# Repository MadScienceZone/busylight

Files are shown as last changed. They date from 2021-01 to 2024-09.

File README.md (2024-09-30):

# ARCHIVED
As of September, 2024, this project is archived. Another project which has long been in the works,
[Readerboard](https://github.com/MadScienceZone/readerboard), defines hardware, firmware, and software
to drive LED matrix displays which happen to also include an 8-LED status indicator display which exactly
mirrors the operation of a Busylight unit. As such, a Readerboard unit is a proper superset of a Busylight
unit, so it made sense to merge the Busylight project into it.

Going forward, the firmware for both Busylights and Readerboards is compiled from a common source code base,
which we consider preferable to maintaining two separate but similar code bases.  Over on the Readerboard
project there are also a number of hardware improvements over the older Busylight units archived here.

# busylight
DIY computer "do not disturb" indicator

This was a weekend project to see if I could take the stuff in my junk drawer and implement a simple light that would show my family members if it was safe to interrupt me without accidentally having their voices or faces appear in a meeting (this is during the work-at-home pandemic restrictions).

## Operation
The light is placed in a convenient and visible location, and displays lights to indicate my current "busy" state.
This version of the Busylight project allows for up to 7 lights of arbitrary colors.

My original used these colors:
* Green: interrupt at will.
* Yellow: interrupt if important (this is shown if I happen to have anything scheduled on my Google calendars, such as a meeting or just some time blocked out to focus on a project)
* Red: in a meeting (this is shown if I'm actually connected to a video conference meeting)
* Flashing red: in a meeting, and my microphone is unmuted
* Flashing blue/red: urgent status
* Strobing green: (along with other lights) low-priority meeting, be aware I'm on camera but interruptions are ok

## Hardware
For the light itself, I grabbed a spare Arduino Pro Micro board, a ULN2003A darlington transistor array chip, and a bunch of LEDs and resistors and threw them together.
I chose resistor values to get a suitable brightness from the LEDs (which varied by color and the voltage ratings of the LEDs; your mileage may vary) without overloading
the USB supply current limits.

The Arduino board and LEDs are powered by the USB port from the host PC, as well as using that connection for the host to send serial commands to control the lights.

To make this easier, I created a shield PCB to neatly interface the high current driver chip to an 8-bin DIN connector for the light tree.

## Software
On the PC, the normal mode of operation is to run the `busylightd` daemon. This monitors a set of Google calendars and reports busy/free times with the green and yellow
lights. It also responds to external signals from other processes which can inform it of other status changes.

In my case, I used [Hammerspoon](https://www.hammerspoon.org) which provides extensible automation capabilities for MacOS systems, including a very handy plugin that detects
when you join or leave a Zoom call, and tracks the state of the mute controls while in the meeting. I just configured that to send the appropriate signals to the
*busylightd* process when those statuses changed.

The upshot of that is that I can leave this running, put busy time on my calendars, join Zoom calls, and so forth, while the light indicator automatically displays
the appropriate colors.

### API Access
To get access to the Google calendar API, you'll need to register with Google and get an API key. If I were distributing this as a pre-made app, I'd include my API key
with the distribution, but as a DIY project, if you make one of these based on my design, you're essentially creating your own app anyway so it makes sense to get a
separate API key for yours.

### Documentation
There's a *busylight(1)* manual page included which explains the setup and operation of the software.

A schematic of how I wired up the hardware is also included, although it's fairly trivial, and can be adjusted to suit your needs.

### GUI Tool
A simple tcl/tk script is supplied which provides a convenient front-end to the *busylight* program, with the addition of task time tracking.

A *blight(1)* manual page is provided to explain it.

# Release notes
See the `CHANGELOG.md` file.

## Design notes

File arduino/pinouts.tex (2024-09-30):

\chapter{Connector Pinouts}
\section{Full-Duplex RS-485 Connection (8p8c Female Modular Jacks)}
\begin{center}
\begin{tikzpicture}[scale=.25]
	\draw [thick] (0,0) -- (0,13) -- (13,13) -- (13,0) -- cycle;
	\draw (2,11) -- (11,11) -- (11,4) -- (9,4) -- (9,3) -- (8,3) -- (8,2) -- (5,2) -- (5,3) -- (4,3) -- (4,4) -- (2,4) -- cycle;
	\foreach \x in {3, 4, 5, 6, 7, 8, 9, 10} {
		\draw (\x,11) -- (\x,8);
	}
	\node [below] at (3,8) {1};
	\node [below] at (10,8) {8};
	\node [right] at (15,12) {\strut 1 Return Data ($+$) (W/Or)};
	\node [right] at (15,10.5) {\strut 2 Return Data ($-$) (Or)};
	\node [right] at (15,9) {\strut 3 Cable Check (W/Gr)};
	\node [right] at (15,7.5)  {\strut 4 Data ($-$) (Bl)};
	\node [right] at (15,6)  {\strut 5 Data ($+$) (W/Bl)};
	\node [right] at (15,4.5)  {\strut 6 Cable Check (Gr)};
	\node [right] at (15,3)  {\strut 7 Data Ground (W/Br)};
	\node [right] at (15,1.5)  {\strut 8 Return Data Ground (Br)};
\end{tikzpicture}
\end{center}

\section{Half-Duplex RS-485 Connection (6p6c Female Modular Jacks)}
\begin{center}
\begin{tikzpicture}[scale=.25]
	\draw [thick] (0,0) -- (0,13) -- (13,13) -- (13,0) -- cycle;
	\draw (2,11) -- (11,11) -- (11,4) -- (9,4) -- (9,3) -- (8,3) -- (8,2) -- (5,2) -- (5,3) -- (4,3) -- (4,4) -- (2,4) -- cycle;
	\foreach \x in {4, 5, 6, 7, 8, 9} {
		\draw (\x,11) -- (\x,8);
	}
	\node [below] at (4,8) {1};
	\node [below] at (9,8) {6};
	\node [right] at (15,12) {\strut 1 Cable Check (W/Gn)};
	\node [right] at (15,10.5) {\strut 2 Data Ground (W/Br)};
	\node [right] at (15,9) {\strut 3 Data ($-$) (Bl)};
	\node [right] at (15,7.5)  {\strut 4 Data ($+$) (W/Bl)};
	\node [right] at (15,6)  {\strut 5 Data Ground (Br)};
	\node [right] at (15,4.5)  {\strut 6 Cable Check (Gn)};
%	\node [right] at (15,3)  {\strut 7 Data Ground};
%	\node [right] at (15,1.5)  {\strut 8 Return Data Ground};
\end{tikzpicture}
\end{center}
%Note that the jacks are labeled ``\mc{IN}'' and ``\mc{OUT/THRU}'' on the board.  This is intended to remind the user
%that these are daisy-chained connections with a signal coming ``in'' to the board on one wire, and on ``through'' to
%the next board in the circuit.% (or ``out'' back to the host PC in the case of responses to query commands).  
%These
%names also mirror the naming conventions used with \acronym{DMX} equipment. 
%
%Electrically, however, the RS-485 serial ``network'' is a single bus running from the host PC to the last Lumos
%controller.  Each controller ``taps'' into the line as it goes by.  This means that, labeling notwithstanding,
%the ``\mc{IN}'' and ``\mc{OUT/THRU}'' jacks are in fact completely identical and interchangeable.
%
%The ``cable check'' lines are simply passed through the Lumos board from input to output, with the expectation that
%the terminator will connect them together.  These lines are not used by Lumos boards at all.  They are provided as
%a convenient way for the host PC interface to verify cable continuity by sending a voltage down one pin all
%the way to the terminator and back on the other pin.  This helps warn the user if a cable becomes disconnected.
%The Lumos front panel circuit board is one example of a circuit which makes use of this feature.
%
%The two grounds on pins 7 and 8 are actually shorted together and connected to the common signal ground
%on the Lumos board.
%
%If connecting a Lumos board to a \acronym{DMX} controller, an adapter cable is needed to connect the
%\acronym{DMX} \acronym{DIN} plug to the 8-pin modular plug used on the Lumos board.  A typical adapter is wired as shown in Table~\ref{tbl:dmx8p}, but check your equipment in case it is different.
%\begin{table}
% \begin{center}
%  \begin{tabular}{ccc}\toprule
%	\bfseries Signal &
%	\bfseries \acronym{DMX} \acronym{DIN} Connector &
%	\bfseries Lumos Modular Connector\\\midrule
%	Ground & 1 & 7, 8 \\
%	Data ($-$) & 2 & 4 \\
%	Data ($+$) & 3 & 5 \\\bottomrule
%  \end{tabular}
%  \caption{Typical Wiring Arrangement to Adapt \acronym{DMX} to Lumos\label{tbl:dmx8p}}
% \end{center}
%\end{table}
%
%\newpage
%
%\section{RS-485 Terminator (8p8c Male Plug)}
%The terminator plug consists of a pair of 120\,$\Omega$ resistors.  One is connected across pins 1--2, and the other
%across pins 4--5.  This provides the proper line termination at the end of the RS-485 chain.  A terminator must
%be plugged in to each end of the chain (but note that often the PC's RS-485 adaptor contains a built-in terminator).
%
%To enable the cable check feature to work, pins 3 and 6 must also be shorted together.
%
%The schematic diagram for the terminator is included below.  Often, the resistors are mounted to a small circuit
%board which fits inside the modular plug, making a self-contained terminator plug.\label{sch:terminator}
%\begin{center}
%	\begin{circuitikz}
%		\draw (0,0) -- (1,0) -- (1,4.5) -- (0,4.5) -- cycle;
%		\node at (.5,.5) {8};
%		\node at (.5,1) {7};
%		\node at (.5,1.5) {6};
%		\node at (.5,2) {5};
%		\node at (.5,2.5) {4};
%		\node at (.5,3) {3};
%		\node at (.5,3.5) {2};
%		\node at (.5,4) {1};
%		\draw (1,4) to[R, l=120\,$\Omega$] (3,4);
%		\draw (3,4) -- (3,3.5) -- (1,3.5);
%		\draw (1,2.5) to[R] (3,2.5);
%		\draw (3,2.5) -- (3,2.0) -- (1,2.0);
%		\draw (1,3) -- (4,3) -- (4,1.5) -- (1,1.5);
%	\end{circuitikz}
%\end{center}
%
%\section{RS-232 Serial Connection (9-pin Female DE-9 Jack)}
%\begin{center}
%	\begin{tikzpicture}[scale=.25]
%		\draw [thick] (0,7) -- (12,7) -- (10,3) -- (2,3) -- cycle;
%		\foreach \x in {2, 4, 6, 8, 10} {
%			\draw (\x, 6) circle (.5);
%		}
%		\foreach \x in {3, 5, 7, 9} {
%			\draw (\x, 4) circle (.5);
%		}
%		\node [above] at (10,7) {1};
%		\node [above] at (2,7) {5};
%		\node [below] at (3,3) {9};
%		\node [below] at (9,3) {6};
%		\node [right] at (14,7) {2 Receive Data\strut};
%		\node [right] at (14,5.5) {3 Transmit Data\strut};
%		\node [right] at (14, 4) {4 Data Terminal Ready\strut};
%		\node [right] at (14, 2.5) {5 Signal Ground\strut};
%		\node [right] at (30, 7) {6 Data Set Ready\strut};
%		\node [right] at (30, 5.5) {7 Request to Send\strut};
%		\node [right] at (30, 4) {8 Clear to Send\strut};
%	\end{tikzpicture}
%\end{center}
%For Lumos boards configured to use RS-232 serial connections to a host PC, a standard 9-pin connector is used,
%with the Lumos board wired as a \acronym{DCE} device.
%
%On the Lumos board, Data Terminal Ready (\acronym{DTR}) and Data Set Ready (\acronym{DSR}) on pins 4 and 6 are shorted
%together, as are Request to Send (\acronym{RTS}) and Clear to Send (\acronym{CTS}) on pins 7 and 8.  This should satisfy
%most communications software which expects to see these signals present, although the Lumos board itself does not
%perform any hardware or software handshaking.
%
%Receive Data (\acronym{RxD}) and Transmit Data (\acronym{TxD}) are named from the point of view of the \acronym{DTE} (host
%PC), so \acronym{TxD} is the wire which carries data from the host PC to the Lumos board.
%
%\section{Sensor Input Terminals (J16)}
%\begin{center}
%	\begin{tikzpicture}[scale=.5]
%		\draw [thick] (.5,.5) -- (5.5,.5) -- (5.5,1.5) -- (.5,1.5) -- cycle;
%		\foreach \x in {1, 2, 3, 4, 5} {
%			\draw (\x,1) circle (.4);
%		}
%		\draw [thick] (4.5, .5) -- (4.5, 1.5);
%		\node [above] at (1,1.5) {$\overline{\hbox{A}}$};
%		\node [above] at (2,1.5) {$\overline{\hbox{B}}$};
%		\node [above] at (3,1.5) {$\overline{\hbox{C}}$};
%		\node [above] at (4,1.5) {$\overline{\hbox{D}}$};
%		\node [above right] at (4.5,1.5) {$\overline{\hbox{PWR CTL}}$};
%		\node [left] at (.5,1) {J16};
%		\node [right] at (5.5,1) {J9};
%		\draw (4,.4) -- (3.8,.1) -- (4.2,.1) -- cycle;
%		\draw (5,.4) -- (4.8,.1) -- (5.2,.1) -- cycle;
%	\end{tikzpicture}
%\end{center}
%If the Lumos controller is built to accommodate one or more sensor inputs, a set of terminals will be installed
%at J16, next to the $\overline{\hbox{\mc{PWR CTL}}}$ output at J9.  These are labeled from left to right (as the board
%is viewed right-side-up from the front) as 
%$\overline{\hbox{\mc{A}}}$,
%$\overline{\hbox{\mc{B}}}$,
%$\overline{\hbox{\mc{C}}}$, 
%and
%$\overline{\hbox{\mc{D}}}$.
%It is important to note that the board's circuitry must be configured for certain inputs to be enabled
%at the time the board is built, and that the board must be configured (using software) to recognize those
%inputs, before they will be usable.
%
%Each input accepts a \acronym{TTL}-level signal.  The lines are pulled up to +5\,V internally.  The board
%can be configured in software to react to the inputs as active-high or active-low.
%
%\section{Logic Output Terminals (J18)}
%\begin{center}
%	\begin{tikzpicture}[scale=.5]
%		\draw [thick] (.5,.5) -- (5.5,.5) -- (5.5,1.5) -- (.5,1.5) -- cycle;
%		\foreach \x in {1, 2, 3, 4, 5} {
%			\draw (\x,1) circle (.4);
%		}
%		\node [above] at (1,1.5) {0};
%		\node [above] at (2,1.5) {1};
%		\node [above] at (3,1.5) {2};
%		\node [above] at (4,1.5) {3};
%		\node [above right] at (4.5,1.5) {GND};
%		\node [left] at (.5,1) {J18};
%	\end{tikzpicture}
%\end{center}
%For experimental use, \acronym{TTL}-level outputs for the first four channels are available on J18.  These
%are active-low outputs, where a ``low'' (0) state indicates that the output should be on, and a ``high''
%(1) state means that the output should be off.  Note that if an output is at a dimmer level other than
%fully on or fully off, the signal will pulse with a duty cycle corresponding to the dimmer level as illustrated
%in Figure~\ref{fig:dutycycle}.
%
%%15
%%14...........
%%13------------
%%12............
%%11
%%10...........
%% 9------------
%% 8............
%% 7
%% 6...........
%% 5------------
%% 4............
%% 3
%% 2...........
%% 1------------
%% 0............
%
%\input dutycycle
%
%\section{ICSP Header (J11)}
%\begin{center}
%	\begin{tikzpicture}[scale=.5]
%		\draw [line width=10] (.6,1)--(5.4,1);
%		\foreach \x in {1, 2, 3, 4, 5} {
%			\foreach \y in {1} {
%				\draw [fill=white] (\x-.2,\y-.2) -- (\x-.2,\y+.2) -- (\x+.2,\y+.2) -- (\x+.2,\y-.2) -- cycle;
%			}
%		}
%		\draw (5.5,1) -- (6,1.25) -- (6,0.75) -- cycle;
%		\node [above] at (1,1.5) {5};
%		\node [above] at (2,1.5) {4};
%		\node [above] at (3,1.5) {3};
%		\node [above] at (4,1.5) {2};
%		\node [above] at (5,1.5) {1};
%		\node [right] at (7, 3.0) {1 $\hbox{V}_{\hbox{\footnotesize DD}}$ (+5\,V)};
%		\node [right] at (7, 2.0) {2 $\hbox{V}_{\hbox{\footnotesize SS}}$ (Ground)};
%		\node [right] at (7, 1.0) {3 $\hbox{V}_{\hbox{\footnotesize PP}}/\overline{\hbox{\mc{MCLR}}}/\overline{\hbox{\mc{RESET}}}$};
%		\node [right] at (15, 3.0) {4 PGD$/\overline{\hbox{\mc{PWR CTL}}}$};
%		\node [right] at (15, 2.0) {5 PGC$/\overline{\hbox{\mc{OPTION}}}$};
%	\end{tikzpicture}
%\end{center}
%
%This header is used for reprogramming a new firmware image onto the microcontroller chip.  Be sure to check the pinout
%used by your programmer before connecting it to this port.  It may be different!
%
%During normal operations, this header may also be used to connect off-board buttons for the reset and option functions.  These
%buttons should be normally open, but connect their respective pins to ground when pushed. 
%Note that the $\overline{\hbox{\mc{PWR CTL}}}$ output is also present on pin~4 of J11 in addition to its normal
%terminal at J9.
%
%
%\section{Voltage Select Headers (J6--J8, J17)}\label{sec:voltagesw}
%\begin{center}
%	\begin{tikzpicture}[scale=.5]
%		%\draw [line width=10] (.6,1)--(4.4,1);
%		\draw [line width=10] (1,.6)--(1,4.4);
%		\draw [line width=10] (5,.6)--(5,4.4);
%		\foreach \y in {1, 2, 3, 4} {
%			\foreach \x in {1, 5} {
%				\draw [fill=white] (\x-.2,\y-.2) -- (\x-.2,\y+.2) -- (\x+.2,\y+.2) -- (\x+.2,\y-.2) -- cycle;
%			}
%		}
%		\node [above] at (1,4.4) {J17};
%		\node [above] at (5,4.4) {J6--J8};
%		\node [left] at (.8,1) {VRO};
%		\node [left] at (.8,2) {+O};
%		\node [left] at (.8,3) {+I};
%		\node [left] at (.8,4) {VRI};
%		\node [left] at (4.8,1) {VRI};
%		\node [left] at (4.8,2) {+I};
%		\node [left] at (4.8,3) {+O};
%		\node [left] at (4.8,4) {VRO};
%
%		\node [right] at (7, 4) {+I: Positive voltage in from power supply};
%		\node [right] at (7, 3) {+O: Positive voltage out to circuit};
%		\node [right] at (7, 2) {VRI: Input to voltage regulator};
%		\node [right] at (7, 1) {VRO: Output from voltage regulator};
%	\end{tikzpicture}
%\end{center}
%J6--J8 are used to select the input voltage supplied to the power control blocks for channels 0--7, 8--15, and 16--23
%respectively.  Likewise, J17 selects the input voltage supplied to the logic portion of the board.  Although the pinouts
%are mirrored between J17 and the others, their operation is the same.  If a regulated +5\,V supply is employed, there is no
%need for the on-board regulator (and in fact it can't function properly unless its input is at least +8\,V), so a jumper
%is placed across the middle two pins (connecting +I and +O), bypassing the voltage regulator entirely.  \emph{In this 
%case, it is critically important that the input voltage be a clean, regulated +5\,V supply.  If this voltage is exceeded,
%permanent damage to the Lumos board will result!}
%
%If +8\,V to +24\,V is attached to an input, the corresponding jumper block needs jumpers installed into the outer two pins,
%connecting +I to VRI and +O to VRO.  This routes the incoming power through the voltage regulator.
%
%\input{voltagedpdt}
%
%\section{Relay Control Connection (26-pin Male IDC Header)}
%%
%%   . . . . . . . . . . . . .
%%   . . . . . . . . . . . . .
%%
%\begin{center}
%	\begin{tikzpicture}[scale=.25]
%		\foreach \x in {1, 2, 3, 4, 5, 6, 7, 8, 9, 10, 11, 12, 13} {
%			\foreach \y in {1, 2} {
%				\draw (\x-.1,\y-.1) -- (\x-.1,\y+.1) -- (\x+.1,\y+.1) -- (\x+.1,\y-.1) -- cycle;
%			}
%		}
%		%\draw         (.4,.4) -- (.4,2.6) -- (13.6,2.6) -- (13.6,.4) -- (.4,.4);
%		\draw         (.4,.4) -- (.4,2.6) -- (13.6,2.6) -- (13.6,.4) -- (8,.4) -- (8,.2) -- (6,.2) -- (6,.4) -- cycle;
%		\draw [thick] (.2,.2) -- (.2,2.8) -- (13.8,2.8) -- (13.8,.2) -- cycle;
%		\node [below] at (1,0) {\strut1};
%		\node [above] at (1,3) {\strut2};
%%		\node [below] at (2,0) {\strut3};
%%		\node [above] at (2,3) {\strut4};
%		\node [below] at (3.5,0) {\strut$\cdots$};
%		\node [above] at (3.5,3) {\strut$\cdots$};
%		\node [below] at (13,0) {\strut 25};
%		\node [above] at (13,3) {\strut 26};
%	\end{tikzpicture}
%\end{center}
%For Lumos controllers built as ``dumb'' relay boards with no built-in logic control of their own, a 26-pin 
%\acronym{IDC} ribbon cable header is installed at J14.  This is used to connect the relays to the controlling circuit (e.g.,
%a Lumos 48-channel controller).  The pinout of this header is:
%\begin{center}
%	\begin{tabular}{rl|rl|rl|rl}
%1&$\overline{\hbox{\mc{SSR23}}}$&8&$\overline{\hbox{\mc{SSR3}}}$&15&Gnd                           &22&$\overline{\hbox{\mc{SSR9}}}$ \\
%2&$\overline{\hbox{\mc{SSR0}}}$&9&$\overline{\hbox{\mc{SSR19}}}$&16&+5\,V                         &23&$\overline{\hbox{\mc{SSR13}}}$ \\
%3&$\overline{\hbox{\mc{SSR22}}}$&10&$\overline{\hbox{\mc{SSR4}}}$&17&$\overline{\hbox{\mc{SSR16}}}$&24&$\overline{\hbox{\mc{SSR10}}}$ \\
%4&$\overline{\hbox{\mc{SSR1}}}$&11&$\overline{\hbox{\mc{SSR18}}}$&18&$\overline{\hbox{\mc{SSR7}}}$&25&$\overline{\hbox{\mc{SSR12}}}$\\
%5&$\overline{\hbox{\mc{SSR21}}}$&12&$\overline{\hbox{\mc{SSR5}}}$&19&$\overline{\hbox{\mc{SSR15}}}$&26&$\overline{\hbox{\mc{SSR11}}}$\\
%6&$\overline{\hbox{\mc{SSR2}}}$&13&$\overline{\hbox{\mc{SSR17}}}$&20&$\overline{\hbox{\mc{SSR8}}}$\\
%7&$\overline{\hbox{\mc{SSR20}}}$&14&$\overline{\hbox{\mc{SSR6}}}$&21&$\overline{\hbox{\mc{SSR14}}}$
%	\end{tabular}
%\end{center}

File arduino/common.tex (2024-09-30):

% @[10]@| Copyright © 1992–2023 by Steven L. Willoughby (AKA MadScienceZone)
% @[11]@| steve@madscience.zone (previously AKA Software Alchemy),
% @[12]@| Aloha, Oregon, USA. All Rights Reserved.
% @[13]@| Distributed under the terms and conditions of the BSD-3-Clause
% @[14]@| License as described in the accompanying LICENSE file distributed
% @[15]@| with GMA.
% @[16]@|
% @[20]@| Redistribution and use in source and binary forms, with or without
% @[21]@| modification, are permitted provided that the following conditions
% @[22]@| are met:
% @[23]@| 1. Redistributions of source code must retain the above copyright
% @[24]@|    notice, this list of conditions and the following disclaimer.
% @[25]@| 2. Redistributions in binary form must reproduce the above copy-
% @[26]@|    right notice, this list of conditions and the following dis-
% @[27]@|    claimer in the documentation and/or other materials provided
% @[28]@|    with the distribution.
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
\usepackage{amsmath}
\usepackage{amssymb}
\usepackage{bbding}
\usepackage{substr}
\usepackage[T1]{fontenc}
\usepackage{tgschola}
\usepackage{ucs}
\usepackage{siunitx}
\usepackage{colortbl}
\usepackage{longtable}
\usepackage{color}
\usepackage{calc}
\usepackage{graphicx}
\usepackage{soul}
\usepackage{xfrac}
\usepackage{wallpaper}
\usepackage{tikz}
\usepackage{verbatim}
\usepackage{algpseudocode}
\usepackage{algorithm}
\usepackage[colorlinks=true,linkcolor=blue]{hyperref}
\usepackage{enumitem}
\makeindex
\newcommand\ix[1]{#1\index{#1}}
%\makeglossary
%\showindexmarks
\nouppercaseheads
%\hideindexmarks
%
% Page Layout Parameters
%
\setstocksize{11in}{8.5in}        % printing on letter stock  8.5x11
%\settrimmedsize{234mm}{180mm}{*}  % trimmed paper dimensions ~7.5x9.5
%
% old sizes
%
%\settrimmedsize{234mm}{184mm}{*}  % trimmed paper dimensions ~7.5x9.5
%\settrims{23mm}{35mm}             % offset into stock of trimmed paper
%\settypeblocksize{182mm}{32pc}{*} % dimensions of type block
%\setlrmargins{*}{27mm}{*}         % margins 27mm from outer edge
%\setulmargins{*}{27mm}{*}         % margins 27mm from bottom edge
%\setheaderspaces{*}{12mm}{*}      % 12mm between header and text baselines
%\setmarginnotes{5mm}{15mm}{2mm}   % margin notes 15mm wide, 5mm from text, 2mm from each other
%
% new sizes
%
%%\settrimmedsize{257mm}{178mm}{*}  % trimmed paper dimensions 
%\settrimmedsize{257mm}{180.5mm}{*}% trimmed paper dimensions 
%%\settrims{12mm}{40mm}             % offset into stock of trimmed paper
%\settrims{12mm}{37mm}             % offset into stock of trimmed paper
%\settypeblocksize{205mm}{31pc}{*} % dimensions of type block
%\setlrmargins{*}{27mm}{*}         % margins 27mm from outer edge
%\setulmargins{*}{27mm}{*}         % margins 27mm from bottom edge
%\setheaderspaces{*}{12mm}{*}      % 12mm between header and text baselines
%\setmarginnotes{5mm}{15mm}{2mm}   % margin notes 15mm wide, 5mm from text, 2mm from each other
\fixpdflayout
%
\trimFrame
\checkandfixthelayout

  \definecolor{chapterboxcolor}{rgb}{.647,.129,.149}%
%\newcommand\defaultchaptercolor{%
%  \definecolor{chapterboxcolor}{rgb}{.051,.278,.631}%
%}
%\defaultchaptercolor
\makeatletter
\newlength\dlf@normtxtw
\setlength\dlf@normtxtw{\textwidth}
\def\myhelvetfont{\def\fdefault{mdput}}
\newsavebox{\feline@chapter}
\newcommand\feline@chapter@marker[1][4cm]{%
\sbox\feline@chapter{%
\resizebox{!}{#1}{\fboxsep=1pt%
%\colorbox{chapterboxcolor}{\color{white}\bfseries\sffamily\thechapter}%
\colorbox{chapterboxcolor}{\color{white}\bfseries\thechapter}%
}}%
\rotatebox{90}{%
\resizebox{%
\heightof{\usebox{\feline@chapter}}+\depthof{\usebox{\feline@chapter}}}%
{!}{\scshape\so\@chapapp}}\quad%
\raisebox{\depthof{\usebox{\feline@chapter}}}{\usebox{\feline@chapter}}%
}
\newcommand\feline@chm[1][4cm]{%
\sbox\feline@chapter{\feline@chapter@marker[#1]}%
\makebox[0pt][l]{% aka \rlap
\makebox[1cm][r]{\usebox\feline@chapter}%
}}
\makechapterstyle{daleif1}{
\renewcommand\chapnamefont{\normalfont\Large\scshape\raggedleft\so}
\renewcommand\chaptitlefont{\normalfont\huge\bfseries\scshape\color{chapterboxcolor}}
\renewcommand\chapternamenum{}
\renewcommand\printchaptername{}
\renewcommand\printchapternum{\null\hfill\feline@chm[2.5cm]\par}
\renewcommand\afterchapternum{\par\vskip\midchapskip}
\renewcommand\printchaptertitle[1]{\chaptitlefont\raggedleft ##1\par}
}
\makeatother
\chapterstyle{daleif1}

%\chapterstyle{veelo}
%\stockletter      % 8.5 x 11  in stock paper size
%\pagestatement    % 8.5 x 5.5 in page size
%\settrimmedsize{9in}{6in}{*}
%\settrims{1in}{1.25in}
%\setlrmarginsandblock{.5in}{.5in}{*}
%\setulmarginsandblock{1in}{1in}{*}
%\trimFrame
%\quarkmarks
%
% Footnote Setup
%
%
% Fix table of contents spacing
% @pnumwidth [1.55em] width of box holding page numbers in TOC
% @tocrmarg  [2.55em] title text indentation from right margin
% @dotsep    [4.5]    math units of space between TOC leader dots.
%
\makeatletter
\renewcommand{\@pnumwidth}{2.5em}
\makeatother
%
%
\begin{document}
\setlength{\epigraphrule}{0pt}
\newcommand\Qauthor[2][]{%
  \\%
  \textnormal{---#2%
    \ifthenelse{\equal{#1}{}}{}{%
      \\%
      {\footnotesize #1}%
    }%
  }%
}
%
% Indexing
% \ix{<text>} typesets <text> and indexes it too (identical in both
%             cases--to get something different, use \index explicitly).
%
% \LJquote[subtext]{author}{quote text}
%    Epigraph (a single quote).  The optional subtext is set smaller
%    in upright shape under the author.  Authors are given an em-dash
%    in caps and small caps fully flush right.  The quote text itself
%    is in Italics in a 40% width paragraph which is itself against the
%    right margin.
%
%    The author's name is indexed.  The following special syntax is
%    recognized for the {author} parameter:
%XXX    <text>      - index <text> after trying to change* to Lastname, First
%XXX    @<text>     - index <text> as-is*
%XXX    /<text>     - typeset <text> but do NOT index (use \index manually)
%
%XXX    <text>!<i>  - typeset as <text>, index as <i> using all the usual
%                     indexing controls in <i>.
%XXX    <text>!     - typeset <text> but do NOT index.
%
%    (*These functions are handled by external scripts which prepare the
%    indexes)
%
% \LJquote*[subtext]{author}{quote text}
%    Alternative for wider quotations (uses 60% width).
%
% \LJquote![subtext]{author}{quote text}
%    Alternative for narrow quotations (uses 25% width).
%
% \LJquotex[subtext]{author}{quote text}{width}
%    Extended and generalized form allowing you to specify your own
%    paragraph width.
%
% \index{...}	Index 
%				entry
%				entry!subentry
%				entry!subentry!subsubentry
%				entry@formatted-entry
%				entry|command			page# in \command{...}
%				entry|see {other-entry}
%				entry|seealso{other-entry}
%				entry@form!sub@form
%				entry|(   ... entry|)    	mark page range
%				"! "@ "| ""			literal !, @, |, "
%
           \newcommand\LJquote[3][]{\LJquotex[#1]{#2}{#3}{0.400\textwidth}}
\WithSuffix\newcommand\LJquote*[3][]{\LJquotex[#1]{#2}{#3}{0.60\textwidth}}
\WithSuffix\newcommand\LJquote![3][]{\LJquotex[#1]{#2}{#3}{0.25\textwidth}}
%
\newcommand\SuppressLjQuoteIndexing{norm}
\newcommand\LJqindex[1]{%
%  \index[quotes]{#1}%
  \index{$1}%
  \renewcommand\SuppressLjQuoteIndexing{nil}%
}
\WithSuffix\newcommand\LJqindex*{\renewcommand\SuppressLjQuoteIndexing{nil}}

\newcommand\LJquotex[4][]{%
  \setlength{\epigraphwidth}{#4}%
  \ifthenelse{\equal{\SuppressLjQuoteIndexing}{norm}}{%
    %\index[quotes]{#2}%
    \index{#2}%
    \IfCharInString{@}{#2}{%
      \IfBeforeSubStringEmpty{@}{#2}{%
%        \def\LJqAuthor{\BehindSubString{@}{#2}}%
	 \def\LJqAuthor{#2}%
      }{%
        \def\LJqAuthor{#2}%
      }%
    }{%
      \def\LJqAuthor{#2}%
    }%
  }{%
    \renewcommand\SuppressLjQuoteIndexing{norm}%
    \def\LJqAuthor{#2}%
  }%
  \ifthenelse{\equal{\LJqAuthor}{}}{%
    \epigraph{{\em #3}}{}}{
    \ifthenelse{\equal{#1}{}}{%
      \epigraph{{\em #3}}{{---\LJqAuthor}}%
    }{%
      \epigraph{{\em #3}}{{---\LJqAuthor}\\
{\footnotesize #1}}%
    }%
  }%
}

% \LJqindex*    Do not index author name at all for next quote
% \LJqindex{@i} Use <i> as index entry for next \LJquote
% \LJqindex{i}  Use <i> as index entry for next \LJquote, changing to Last, First format
% \LJquote[work]{author}{text}  Set quote and index author in Last, First format
% \LJquote[work]{@author}{text} Set quote and index author as-is

\maxsecnumdepth{chapter}
% SourceCode environment:
%   Typesets source code in a verbatim box.
%
\newenvironment{SourceCode}{\boxedverbatim}{\endboxedverbatim}
\newenvironment{SourceCode*}{\begin{tcolorbox}\verbatim}{\endverbatim\end{tcolorbox}}
%
% Coding environment:
%   Code verbatim inside |bars|
%   Variables in \Var[*]{...} command  * form uses <> brackets around name
%
% Coding* puts the text in a colored box
% Coding! is like Coding* but uses ` instead of | to toggle verbatim text
% Coding: is like Coding! but is flush left
%   
\newenvironment{Coding}{\MakeShortVerb{\|}}{\DeleteShortVerb{\|}}
\newenvironment{Coding*}{\begin{tcolorbox}\MakeShortVerb{\|}}{\DeleteShortVerb{\|}\end{tcolorbox}}
\newenvironment{Coding!}{\begin{tcolorbox}\MakeShortVerb{\`}}{\DeleteShortVerb{\`}\end{tcolorbox}}
\newenvironment{Coding:}{\begin{tcolorbox}\MakeShortVerb{\`}\begin{flushleft}}{\end{flushleft}\DeleteShortVerb{\`}\end{tcolorbox}}
\newcommand\Var[1]{{\itshape #1\/}}
\WithSuffix\newcommand\Var*[1]{$\langle${\itshape #1\/}$\rangle$}
%
% \LJversal{versal}{first word(s)}
%   Begin a chapter paragraph.  This is just like \LJstart but without the
%   meta-post information being printed.
%   (In fact, \LJstart calls \LJversal to do the initial text.)
%
\newcommand\LJversal[2]{%
 \ifthenelse{\equal{#1}{A}}{%
  \lettrine[lines=3,findent=-1.1em,nindent=.9em,slope=.6em]{#1}{#2}%---------------A
 }{%
  \ifthenelse{\equal{#1}{B}}{%
   \lettrine[lines=3,findent=-.4em]{#1}{#2}%---------------------------------------B
  }{%
   \ifthenelse{\equal{#1}{C}}{%
    \lettrine[lines=3,findent=-.2em]{#1}{#2}%--------------------------------------C
   }{%
    \ifthenelse{\equal{#1}{D}}{%
     \lettrine[lines=3,findent=-.4em]{#1}{#2}%-------------------------------------D
    }{%
     \ifthenelse{\equal{#1}{E}}{%
      \lettrine[lines=3,findent=-.2em]{#1}{#2}%------------------------------------E
     }{%
      \ifthenelse{\equal{#1}{G}}{%
       \lettrine[lines=3,findent=-.3em]{#1}{#2}%-----------------------------------G
      }{%
       \ifthenelse{\equal{#1}{I}}{%
        \lettrine[lines=3,findent=-.1em]{#1}{#2}%----------------------------------I
       }{%
        \ifthenelse{\equal{#1}{K}}{%
         \lettrine[lines=3,findent=+.1em]{#1}{#2}%---------------------------------K
        }{%
         \ifthenelse{\equal{#1}{L}}{%
          \lettrine[lines=3,findent=-1.1em,nindent=1.5em]{#1}{#2}%-----------------L
         }{%
          \ifthenelse{\equal{#1}{O}}{%
           \lettrine[lines=3,findent=-.3em]{#1}{#2}%-------------------------------O
          }{%
           \ifthenelse{\equal{#1}{Q}}{%
            \lettrine[lines=3,findent=-.3em]{#1}{#2}%------------------------------Q
           }{%
            \ifthenelse{\equal{#1}{R}}{%
             \lettrine[lines=3,findent=-.3em]{#1}{#2}%-----------------------------R
            }{%
             \ifthenelse{\equal{#1}{S}}{%
              \lettrine[lines=3,findent=-.2em]{#1}{#2}%----------------------------S
             }{%
              \ifthenelse{\equal{#1}{V}}{%
               \lettrine[lines=3,findent=+.1em,nindent=0em,slope=-.5em]{#1}{#2}%---V
              }{%
               \ifthenelse{\equal{#1}{W}}{%
                \lettrine[lines=3,nindent=-.1em,slope=-.4em]{#1}{#2}%--------------W
               }{%
                \ifthenelse{\equal{#1}{Y}}{%
                 \lettrine[lines=3,findent=+.1em,nindent=0em,slope=-.5em]{#1}{#2}%-Y
                }{%
                 \lettrine[lines=3]{#1}{#2}%---------------------------------------*
	        }%
               }%
	      }%
	     }%
            }%
           }%
          }%
         }%
        }%
       }%
      }%
     }%
    }%
   }%
  }%
 }%
}

%
% \LJimg[options]{filename}
%   Place an inline EPS image here in the text (this needs refinement)
%
\newcommand\LJimg[2][]{%
  \ifthenelse{\equal{#2}{}}{%
    \emph{XXX Image? #1 #2}%
    \typeout{Missing image name in LJimg!}%
  }{%
    \ifthenelse{\boolean{pdf}}{%
      \ifthenelse{\equal{#1}{}}{%
        %\epsfig{file=images/#2, width=\textwidth}%
	%
      }{%
        %\epsfig{file=images/#2, #1}%
	%
      }%
    }{%
      \ifthenelse{\equal{#1}{}}{%
        %\epsfig{file=eps/#2.eps, width=\textwidth}%
	%
      }{%
        %\epsfig{file=eps/#2.eps, #1}%
	%
      }%
    }%
  }%
}% 
%
%
% \URLref[*][text]{url}
%   Refer to a URL somehow (as <a href="url">text</a> would have been)
%   Starred form uses 2nd level of footnotes (for use within a footnote)
%
\newcommand\URLref[2][]{#1\footnote{\URL{#2}}}
\WithSuffix\newcommand\URLref*[2][]{#1\footnoteB{\URL{#2}}}
%
% \acronym{letters}
% \mc{letters}
%   Typesets all-caps in slightly smaller font.  \mc just does the
%   typesetting, while \acronym also adds an entry in the main index
%   for the term (maybe someday we'll add to the glossary as well).
%
\newcommand\acronym[1]{{\smaller #1}\index{#1@\acronym*{#1}}}
\newcommand\Acronym[2]{#1{\smaller #2}\index{#1#2@#1{\smaller#2}}}
\WithSuffix\newcommand\acronym*[1]{{\smaller #1}}
\WithSuffix\newcommand\Acronym*[2]{#1{\smaller #2}}
\newcommand\mc[1]{{\smaller #1}}
%
% \starsep[symbol]
%   Star paragraph section separator.  The default symbol is
%   a fancy asterisk from the dingbats font.
%
\newcommand\starsep[1][\Asterisk]{
	\medskip
	\centerline{#1\qquad#1\qquad#1\qquad#1}
	\medskip
}

%
% unfinished
%
%\tracingmacros=1
\newcommand\strong[1]{{\bfseries #1}}
\newcommand\TM{\texttrademark}
\newcommand\work[1]{\emph{#1}\index{#1@\work*{#1}}}
\WithSuffix\newcommand\work*[1]{\emph{#1}}
\WithSuffix\newcommand\work:[2]{\work*{#1}\index{#2@\work*{#2}}}
%\WithSuffix\newcommand\worki[2]{\emph{#1 #2}\index{#2, #1@\emph{#2, #1}}}
\newcommand\URL[1]{{\ttfamily #1}}

\newenvironment{LJwrapimg}[3]{%
 \begingroup\setlength\intextsep{0pt}%
  \begin{wrapfigure}{#1}{#2}%
   \LJimg[width=#2]{#3}%
  \end{wrapfigure}%
}{%
 \par\endgroup%
}

\newcommand\z[1]{{\ttfamily#1}}
\newcommand\zb[1]{{\ttfamily\bfseries#1}}

% Based on post from tex.stackexchange.com from Gonzalo Medina
%\newlength\widest
%\makeatletter
%\NewEnviron{ldescription}{%
% \vbox{%
%  \global\setlength\widest{0pt}%
%  \def\item[##1]{%
%   \settowidth\@tempdima{\textbf{##1}}%
%   \ifdim\@tempdima>\widest\global\setlength\widest{\@tempdima}\fi%
%  }%
%  \setbox0=\hbox{\BODY}%
% }
% \begin{description}[
%   leftmargin=\dimexpr\widest+0.5em\relax,
%   labelindent=0pt,
%   labelwidth=\widest]
%  \BODY
%  \end{description}%
%}
%\makeatother
\newenvironment{ldescription}[1]{\begin{description}[leftmargin=#1+.5em,labelindent=0pt,labelwidth=#1]}{\end{description}}
%
% the NewContent environment shows material recently added to the document.
%
\newenvironment{NewContent}{\begingroup\color{blue}}{\endgroup}

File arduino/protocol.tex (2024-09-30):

% TODO: add support for Lumos-compatible RS-485 protocol
\input common
\frontmatter
\definecolor{reservedslot}{gray}{0.8}
\newcommand\api{\acronym{API}}
\newcommand\pc{\acronym{PC}}
\newcommand\cli{\acronym{CLI}}
\newcommand\ascii{\acronym{ASCII}}
\newcommand\led{\acronym{LED}}
\newcommand\codetype[1]{\z{#1}}
\newcommand\ixz[1]{\index{#1@\z{#1}}\z{#1}}
\newcommand\tUnused{\cellcolor{gray!50}}
\newcommand\tControl{\cellcolor{yellow!50}}
\newcommand\tForbidden{\cellcolor{red!50}}
\newcommand\tSpecial{\cellcolor{blue!25}}
%\colorlet{tableheader}{blue!40}
%\colorlet{tablesubhead}{blue!20}
%\colorlet{recordbox}{blue!15}
%\colorlet{recordtext}{black}
%\usetikzlibrary{positioning,shapes,shadows,arrows}
%\tikzstyle{program}=[rectangle, draw=black, rounded corners, fill=recordbox, drop shadow,
%	anchor=north, text=recordtext, text width=2cm]
%\tikzstyle{instance}=[rectangle, draw=black, rounded corners, fill=green!15, drop shadow,
%	anchor=north, text=black, text width=3cm]
%\tikzstyle{line}=[-, thick]
%\tikzstyle{myarrow}=[->, >=triangle 45, thick]
\hypersetup{
	pdftitle={Busylight User's Guide},
	pdfkeywords={Open Source Status Light Hardware and Software},
	pdfauthor={Steve Willoughby / Mad Science Zone},
	pdfsubject={Busylight Project Documentation * (c) 2023 * Creative Commons Licensing (See Document for details)},
	colorlinks=true,
	linkcolor=blue!30!black,
}
\thispagestyle{empty}
	\begin{center}
		\Huge Busylight \\ User's Guide \\
		WORKING\\DRAFT
	\end{center}

\vfill
%\end{flushright}
\newpage
The information in this document, and the hardware and software it describes, are hobbyist
works created as an educational exercise and as a matter of personal interest for recreational
purposes.

It is not to be considered an industrial-grade or retail-worthy product.
It is assumed that the user has the necessary understanding and skill to use it appropriately.  The author makes NO
representation as to suitability or fitness for any purpose whatsoever, and disclaims any and all liability or 
warranty to the full extent permitted by applicable law.  It is explicitly not designed for use where the safety
of persons, animals, property, or anything of real value depends on the correct operation of the software.

\strut\vfill

\begin{center}\bfseries
	For busylight hardware version 1.0.2, and firmware version 2.0.0.
\end{center}

\strut\vfill

\noindent Copyright \copyright\ 2023 by Steven L. Willoughby
(aka MadScienceZone), Aloha, Oregon, USA. All Rights Reserved.
This document is released under the terms and conditions of the
Creative Commons ``Attribution-NoDerivs 3.0 Unported'' license.
In summary, you are free to use, reproduce, and redistribute this 
document provided you give full attribution to its author and do not
alter it or create derivative works from it.  See
\begin{center}
\href{http://creativecommons.org/licenses/by-nd-3.0}{http://creativecommons.org/licenses/by\-nd\-/\-3.0/} 
\end{center}
for the full set of licensing terms.

\begin{center}
\LJimg[width=.25in]{cc}\LJimg[width=.25in]{by}\LJimg[width=.25in]{nd}
\end{center}

\newpage
\tableofcontents
\newpage
\listoffigures
\listoftables
\mainmatter

%%%%%%%%%%%%%%%%%%%%%%%%%%%%%%%%%%%%%%%%%%%%%%%%%%%%%%%%%%%%%%%%%%%%%%%%%%%%%%%%%%%%%%%%%%%%%%%%%%%%
%  ____  ____   ___ _____ ___   ____ ___  _     
% |  _ \|  _ \ / _ \_   _/ _ \ / ___/ _ \| |    
% | |_) | |_) | | | || || | | | |  | | | | |    
% |  __/|  _ <| |_| || || |_| | |__| |_| | |___ 
% |_|   |_| \_\\___/ |_| \___/ \____\___/|_____|
%
\chapter{Protocol Description}\label{chap:protocol}
{\setlength{\epigraphwidth}{.5\textwidth}
\epigraph{Protocol is etiquette with a government expense account.}{---Judith Martin}}
\LJversal{T}{he protocol} used to control the busylight device is very simple.
Commands are expressed largely in plain \ascii\ characters and are executed immediately
as they are received.\footnote{Technically, they may even be executed \emph{while} they
are being received.}
%It is not necessarily required for a command to be fully received first,
%so it is possible that the unit will have started operating on part of the command (e.g.,
%moving the current cursor column position) even if the rest of the command could not be
%performed.

\section{USB vs. RS-485}
The protocol used to send commands to the busylight is different depending on
whether the host is sending directly to a single device over a \acronym{USB}
cable, or to (possibly) multiple devices over an RS-485 bus network.

This was designed for the Adruino Nano controller, which only has a single
\acronym{USART}, so the busylight will differentiate between \acronym{USB}
and RS-485 commands from their respective formats. On other units with multiple
serial ports, one is dedidated to the RS-485 network.

\subsection{USB}
A busylight connected via \acronym{USB} accepts the commands just as documented
below, with the addition that each such command is terminated by a 
\z{\textasciicircum D} byte (hex value \z{04}$_{16}$).
\begin{center}
\begin{bytefield}[endianness=little,bitwidth=0.11111\textwidth]{9}
	\bitbox[]{1}{\scriptsize0}&
	\bitbox[]{1}{\scriptsize\dots}&
	\bitbox[]{1}{\scriptsize$n-1$}&
	\bitbox[]{1}{\scriptsize$n$}\\
	\bitbox{3}{\Var*{command}}&
	\bitbox{1}{\z{\textasciicircum D}}
\end{bytefield}
\end{center}

If there is an error parsing or executing a command, the busylight will ignore
all subsequent input until a \z{\textasciicircum D} is received, whereupon it will
expect to see the start of another command. Thus, \z{\textasciicircum D} may not
appear in any transmitted data except to terminate commands.

\subsection{RS-485}
Commands sent over RS-485 are intended to target one or more of a set of
connected busylight units over a network which may also contain other Lumos-protocol-compatible
devices, so they use a protocol compatible with that use case.

Each command begins with one of the following binary headers, depending on the
set of target busylight units which should obey the command.

\subsubsection{Single Target or All Devices}
To send a command to a single unit, begin with a single byte encoded as:
\begin{center}
	\begin{bytefield}[endianness=big]{8}
		\bitheader{0-7} \\
		\bitbox{1}{\z{1}}&
		\bitbox[tbl]{1}{\z0}&
		\bitbox[tb]{1}{\z0}&
		\bitbox[tbr]{1}{\z1}&
		\bitbox{4}{\Var*{ad}}
	\end{bytefield}
\end{center}
where \Var*{ad} is the unit's address on the bus, which must be a value in the
range 0--15. This byte is followed by any command as described below. 
If the global address \Var{ad$_G$} is given as the \Var*{ad} value, then all busylight units
which have that set as their global address will obey the command.

\subsubsection{Multiple Targets}
Alternatively, a command may be targetted to multiple units by starting the command
with a multi-byte code:
\begin{center}
	\begin{bytefield}[endianness=big]{8}
		\bitheader{0-7} \\
		\bitbox{1}{\z{1}}&
		\bitbox[tbl]{1}{\z0}&
		\bitbox[tb]{1}{\z1}&
		\bitbox[tbr]{1}{\z1}&
		\bitbox{4}{\Var*{ad$_G$}}\\
		\bitbox{1}{\z0}&
%		\bitbox{3}{\color{reservedslot}\rule{\width}{\height}}&
%		\bitbox{4}{\Var*{n}}\\
		\bitbox{1}{\z0}&
		\bitbox{6}{\Var*{n}}\\
		\bitbox{1}{\z0}&
%		\bitbox{3}{\color{reservedslot}\rule{\width}{\height}}&
%		\bitbox{4}{\Var*{ad$_0$}}\\
		\bitbox{1}{\z0}&
		\bitbox{6}{\Var*{ad$_0$}}\\
		\bitbox[]{8}{$\vdots$\strut}\\
		\bitbox{1}{\z0}&
%		\bitbox{3}{\color{reservedslot}\rule{\width}{\height}}&
%		\bitbox{4}{\Var*{ad$_{n-1}$}}
		\bitbox{1}{\z0}&
		\bitbox{6}{\Var*{ad$_{n-1}$}}
	\end{bytefield}
\end{center}
where \Var*{ad$_G$} is the ``global'' device address which signals busylight units
generally (see the \z= command below).
This will send to the \Var*{n} devices addressed as \Var*{ad$_0$} through \Var*{ad$_{n-1}$}.

Note that the address of a unit is constrained to four bits (values 0--15) in the regular
command header, but the address values listed here are seven bits wide (values 0--63).
This allows you to give busylight devices address above 15, but if you do this, then
this multiple-target header must be used to send commands to them, since their addresses
won't fit in the shorter single-byte header.

\subsubsection{All Off}
As a special case, the single byte
\begin{center}
	\begin{bytefield}[endianness=big]{8}
		\bitheader{0-7} \\
		\bitbox{1}{\z{1}}&
		\bitbox[tbl]{1}{\z0}&
		\bitbox[tb]{1}{\z0}&
		\bitbox[tbr]{1}{\z0}&
		\bitbox{4}{\Var*{ad}}
	\end{bytefield}
\end{center}
will cause the busylight addressed as \Var*{ad} to turn off all \led s.
If \Var*{ad} is the \Var{ad$_G$} address, then all busylight units will turn off
all \led s.

No other command bytes need to follow; this byte is sufficient to turn off
the unit(s).

\subsubsection{Subsequent Command Bytes}
All subsequent bytes which follow the above binary headers \emph{must} have their
\acronym{MSB} cleared to \z0. 

To cover cases where a value sent as part of a command must have the \acronym{MSB}
set, we use the following escape codes:
\begin{itemize}
	\item A hex byte \z{7E}$_{16}$ causes the next byte received to have its
		\acronym{MSB} set upon receipt.
	\item A hex byte \z{7F}$_{16}$ causes the next byte to be accepted without
		any further interpretation.
\end{itemize}
Thus, the byte \z{C4}$_{16}$ is sent as the two-byte sequence \z{7E~44},
while a literal \z{7E} is sent as \z{7F~7E} and a literal \z{7F} as \z{7F~7F}.

If there is an error parsing or executing a command, the busylight will ignore
all subsequent input until a byte arrives with its \acronym{MSB} set to \z1,
whereupon it will expect to see the start of another command. 

\section{Command Summary}
\begin{table}
	\begin{center}
		\begin{tabular}{cll}\toprule
			\multicolumn{1}{c}{\bfseries Command}&
			\multicolumn{1}{c}{\bfseries Description}&
			\multicolumn{1}{c}{\bfseries Notes}\\\midrule
			\z{?} & Query discrete \led\ status & [1] [2]\\
			\z{=} & Set operational parameters & [2]\\
			\z{*} & Strobe \led s in Sequence & \\
			\z{F} & Flash \led s in Sequence & \\
			\z{L} & Light one or more \led s steady & \\
			\z{Q} & Query device status & [1] [2]\\
			\z{S} & Light one \led\ steady & \\
			\z{X} & All \led s off & \\
			\bottomrule
			\multicolumn{3}{l}{\footnotesize [1] Sends response}\\
			\multicolumn{3}{l}{\footnotesize [2] \acronym{USB} only}\\
		\end{tabular}
		\caption{Summary of All Commands\label{tbl:commands}}
	\end{center}
\end{table}

%Although the rev 2 hardware supports the ability to enable the RS-485 transmitter and send data back onto the network,
%this is not currently implemented by the firmware, and the intent is to have all devices listen passively to RS-485 traffic
%at all times.

\section{\z{*}---Strobe Lights in Sequence}
\begin{center}
\begin{bytefield}[endianness=little,bitwidth=0.11111\textwidth]{7}
%	\bitheader{0-3} \\
	\bitbox[]{1}{\scriptsize0}&
	\bitbox[]{1}{\scriptsize1}&
	\bitbox[]{1}{\scriptsize2}&
	\bitbox[]{1}{\scriptsize3}&
	\bitbox[]{1}{\scriptsize\dots}&
	\bitbox[]{1}{\scriptsize$n$}&
	\bitbox[]{1}{\scriptsize$n+1$}\\
	\bitbox{1}{\z{*}} &
	\bitbox[tlb]{1}{\Var*{led$_0$}} &
	\bitbox[tb]{1}{\Var*{led$_1$}} &
	\bitbox[tb]{1}{\Var*{led$_2$}} &
	\bitbox[tb]{1}{$\cdots$} &
	\bitbox[tbr]{1}{\Var*{led$_{n-1}$}} &
	\bitbox{1}{\z\$}
\end{bytefield}
\end{center}

Each \Var*{led} value is an \ascii\ character corresponding to a discrete
\led\ as shown in Table~\ref{tbl:lightcodes}. An \Var*{led} value of ``\z{\_}'' means
there is no \led\ illuminated at that point in the sequence.

This command functions identically to the \z{F} command (see below), except that the lights
are ``strobed'' (flashed very briefly with a pause between each light in the sequence).

\section{\z{=}---Set Operational Parameters}
\begin{center}
\begin{bytefield}[endianness=little,bitwidth=0.11111\textwidth]{8}
%	\bitheader{0-3} \\
	\bitbox[]{1}{\scriptsize0}&
	\bitbox[]{1}{\scriptsize1}&
	\bitbox[]{1}{\scriptsize2}&
	\bitbox[]{1}{\scriptsize3}&
	\bitbox[]{1}{\scriptsize4}\\
	\bitbox{1}{\z{=}} &
	\bitbox{1}{\Var*{ad}}&
	\bitbox{1}{\Var*{uspd}}&
	\bitbox{1}{\Var*{rspd}}&
	\bitbox{1}{\Var*{ad$_G$}}
\end{bytefield}
\end{center}

This command sets a few operational parameters for the unit. Once set, these will be persistent across
power cycles and reboots.

If the \Var*{ad} parameter is ``\z{\_}'' then the RS-485 interface is disabled entirely. Otherwise it is a
value from 0--63 encoded as described in Table~\ref{tbl:int063}. This enables the RS-485 interface and assigns
this unit's address to \Var*{ad}. Note that if you assign an address greater than 15 you can only address
the unit via multiple-target headers or via the global address.

The baud rate for the \acronym{USB} and RS-485 interfaces is set by the \Var*{uspd} and \Var*{rspd} values
respectively. Each is encoded as per Table~\ref{tbl:baudcodes}.

The \Var*{ad$_G$} value is an address in the range 0--15 which is not assigned
to any other device on the RS-485 network. This is used to signal that all
busylight units should pay attention to the start of the command because it might
target them either as part of a list of specific busylight units or because the
command is intended for all busylight units at once. This is encoded in the 
same way as \Var*{ad}.
If you only have one busylight or do no wish to assign a global address,
just set \Var*{ad$_G$} to the same value as \Var*{ad}.

This command may only be sent over the \acronym{USB} port.

By default, an unconfigured busylight is set to 9,600 baud with the RS-485 port disabled.
\begin{table}
	\begin{center}
		\begin{tabular}{crl}\toprule
			\bfseries Code & \multicolumn{1}{c}{\bfseries Speed} \\\midrule
			\z0 & 300\\
			\z1 & 600\\
			\z2 & 1,200\\
			\z3 & 2,400\\
			\z4 & 4,800\\
			\z5 & 9,600 & (default)\\
			\z6 & 14,400\\
			\z7 & 19,200\\
			\z8 & 28,800\\
			\z9 & 31,250\\
			\z{A} & 38,400\\
			\z{B} & 57,600\\
			\z{C} & 115,200\\
		\bottomrule
		\end{tabular}
		\caption{Baud Rate Codes\label{tbl:baudcodes}}
	\end{center}
\end{table}

\section{\z?---Query Discrete \led\ Status}
\begin{center}
\begin{bytefield}[endianness=little,bitwidth=0.11111\textwidth]{1}
	\bitheader{0} \\
	\bitbox{1}{\z{?}}
\end{bytefield}
\end{center}

This command causes the unit to send a status report back to the host to indicate
what the discrete \led s are currently showing. This response has the form:

\medskip

\begin{center}\begin{bytefield}[endianness=little,bitwidth=0.11111\textwidth]{9}
	\bitheader{0-8} \\
	\bitbox{1}{\z{L}} &
	\bitbox[tbl]{1}{\Var*{led$_0$}} &
	\bitbox[tb]{1}{\Var*{led$_1$}} &
	\bitbox[tb]{1}{\Var*{led$_2$}} &
	\bitbox[tb]{1}{\Var*{led$_3$}} &
	\bitbox[tb]{1}{\Var*{led$_4$}} &
	\bitbox[tb]{1}{\Var*{led$_5$}} &
	\bitbox[tb]{1}{\strut$\cdots$} &
	\bitbox[tbr]{1}{\Var*{led$_{n-1}$}} \\
	\bitbox{1}{\z{\$}} &
	\bitbox{1}{\z{F}} &
	\bitbox{7}{flasher status (see below)} \\
	\bitbox{1}{\z{\$}} &
	\bitbox{1}{\z{S}} &
	\bitbox{7}{strober status (see below)} \\
	\bitbox{1}{\z{\$}} &
	\bitbox{1}{\z{\textbackslash n}}
\end{bytefield}
\end{center}

Each \Var*{led$_x$} value is a single character which is ``\z{\_}'' if the corresponding \led\ is
off, or the \led's color code or position number if it is on. a ``\z{?}'' is sent if the value set
for the \led\ is invalid. One such value is sent for each \led\ installed
in the unit (typically seven for busylight units), followed by a ``\z{\$}'' to mark the end of the list.

The flasher and strober status values are variable-width fields which indicate the
state of the flasher (see \z{F} command) and strober (see \z{*} command) functions.
In each case, if there is no defined sequence, the status field will be:

\medskip

\begin{center}\begin{bytefield}[endianness=little,bitwidth=0.11111\textwidth]{2}
	\bitheader{0-1} \\
	\bitbox{1}{\Var*{run}} &
	\bitbox{1}{\strut\z{\_}}
\end{bytefield}
\end{center}

\smallskip

\noindent Otherwise, the state of the flasher or strober unit is indicated by:

\medskip

\begin{center}\begin{bytefield}[endianness=little,bitwidth=0.11111\textwidth]{7}
%	\bitheader{0-6} \\
	\bitbox[]{1}{\scriptsize0}&
	\bitbox[]{1}{\scriptsize1}&
	\bitbox[]{1}{\scriptsize2}&
	\bitbox[]{1}{\scriptsize3}&
	\bitbox[]{1}{\scriptsize4}&
	\bitbox[]{1}{\scriptsize\dots}&
	\bitbox[]{1}{\scriptsize$n+3$}\\
	\bitbox{1}{\Var*{run}} &
	\bitbox{1}{\Var*{pos}} &
	\bitbox{1}{\z{@}} &
	\bitbox[tbl]{1}{\Var*{led$_0$}} &
	\bitbox[tb]{1}{\Var*{led$_1$}} &
	\bitbox[tb]{1}{$\cdots$} &
	\bitbox[tbr]{1}{\Var*{led$_{n-1}$}} 
\end{bytefield}
\end{center}

In either case, \Var*{run} is the \ascii\ character ``\z{S}'' if the unit is
stopped or ``\z{R}'' if it is currently running.  If there is a defined sequence,
\Var*{pos} indicates the 0-origin position within the sequence of the light currently
being flashed or strobed, encoded as described in Table~\ref{tbl:int063}. 
The \Var*{led$_x$} values are as allowed for the \z{F} or \z{*}
command that set the sequence. (Regardless of the actual \z{F} or \z{*} command parameters,
the report will show symbolic color codes where possible, or numeric position codes otherwise.)

The status message sent to the host is terminated by a newline character (hex byte \z{0A}),
indicated in the protocol description above as ``\z{\textbackslash n}''.
\begin{table}
	\begin{center}
		\begin{tabular}{cc|cc}\toprule
			\multicolumn{1}{c}{\bfseries Value} &
			\multicolumn{1}{c}{\bfseries Code} &
			\multicolumn{1}{c}{\bfseries Value} &
			\multicolumn{1}{c}{\bfseries Code} \\\midrule
			0--9 & \z0--\z9 & 17--42 & \z{A}--\z{Z} \\
			10 & \z: & 43 & \z[ \\
			11 & \z; & 44 & \z\textbackslash \\
			12 & \z< & 45 & \z] \\
			13 & \z= & 46 & \z\textasciicircum \\
			14 & \z> & 47 & \z{\_} \\
			15 & \z? & 48 & \z` \\
			16 & \z@ & 49--63 & \z{a}--\z{o} \\
			\bottomrule
		\end{tabular}

		{\footnotesize (Each code is the numeric value plus 48.)}
		\caption{\ascii\ Encoded Integer Values (0--63)\label{tbl:int063}}
	\end{center}
\end{table}

This command may only be sent on the \acronym{USB} port.

\section{\z{F}---Flash Lights in Sequence}
\begin{center}
\begin{bytefield}[endianness=little,bitwidth=0.11111\textwidth]{7}
%	\bitheader{0-7} \\
	\bitbox[]{1}{\scriptsize0}&
	\bitbox[]{1}{\scriptsize1}&
	\bitbox[]{1}{\scriptsize2}&
	\bitbox[]{1}{\scriptsize3}&
	\bitbox[]{1}{\dots}&
	\bitbox[]{1}{\scriptsize$n$}&
	\bitbox[]{1}{\scriptsize$n+1$}\\
	\bitbox{1}{\z{F}} &
	\bitbox[tbl]{1}{\Var*{led$_0$}} &
	\bitbox[tb]{1}{\Var*{led$_1$}} &
	\bitbox[tb]{1}{\Var*{led$_2$}} &
	\bitbox[tb]{1}{$\cdots$} &
	\bitbox[tbr]{1}{\Var*{led$_{n-1}$}} &
	\bitbox{1}{\z\$}
\end{bytefield}
\end{center}

Each \Var*{led} value is an \ascii\ character corresponding to a discrete
\led\ as shown in Table~\ref{tbl:lightcodes}. Note that the assignment of colors
to these \led s is dependent on your particular hardware being assembled that way.
As an open source project, of course, you (or whomever assembled the unit) may choose any
color scheme you like when building the board.

An \Var*{led} value of ``\z{\_}'' means there is to be no \led\ illuminated at the
corresponding position in the sequence.
\begin{table}
	\begin{center}
		\begin{tabular}{ccl}\toprule
			\multicolumn{1}{c}{\bfseries Code*}&
			\multicolumn{1}{c}{\bfseries Light}&
			\multicolumn{1}{c}{\bfseries Color}\\\midrule
			\z{B} & L$_0$ & blue \\
			\z{R} & L$_1$ & red \\
			\z{r} & L$_2$ & red \\
			\z{Y} & L$_3$ & yellow \\
			\z{G} & L$_4$ & green \\
			\z{\_}& --- & (no \led/off) \\
			\z0--\z9&L$_0$--L$_9$&\led\ installed at physical position 0--9\\
			\bottomrule
		\end{tabular}\\
		{\footnotesize *If a unit is built with different colors in these positions, the letter codes\\ for those
		\led s will match the custom color arrangement for that unit.}
		\caption{Discrete \led\ Codes and Colors\label{tbl:lightcodes}}
	\end{center}
\end{table}

Up to 64 \Var*{led} codes may be listed. The unit will cycle through the sequence, lighting each
specified \led\ briefly before moving on to the next one. The sequence is repeated
forever in a loop until an \z{L}, \z{S} or \z{X} command is received. 

If only one \Var*{led} is specified, that light will be flashed on and off.
Setting an empty
sequence (no codes at all) stops the flasher's operation.

The sequence is terminated by either a dollar-sign (``\z{\$}'') character or the
escape control character (hex byte \z{1B}), indicated in the protocol diagram above
simply as ``\z{\$}''.
			
This command may be given in upper- or lower-case (``\z{f}'' or ``\z{F}'').

\section{\z{Q}---Query Device Status}
\begin{center}
\begin{bytefield}[endianness=little,bitwidth=0.11111\textwidth]{1}
	\bitheader{0} \\
	\bitbox{1}{\z{Q}} 
\end{bytefield}
\end{center}

This command causes the unit to send a status report back to the host to indicate
the general status of the device except for the discrete \led\ display which
may be queried using the \z? command. The response has the form:

\medskip

\begin{center}
\begin{bytefield}[endianness=little,bitwidth=0.11111\textwidth]{9}
%	\bitheader{0-8} \\
	\bitbox[]{1}{\scriptsize0}&
	\bitbox[]{1}{\scriptsize1}&
	\bitbox[]{1}{\scriptsize2}&
	\bitbox[]{1}{\scriptsize3}&
	\bitbox[]{1}{\scriptsize4}&
	\bitbox[]{1}{\scriptsize5}&
	\bitbox[]{1}{\scriptsize6}&
	\bitbox[]{1}{\scriptsize7}&
	\bitbox[]{1}{\scriptsize8}\\
	\bitbox{1}{\z{Q}} &
	\bitbox{1}{\Var*{model}} &
	\bitbox{1}{\z{=}} &
	\bitbox{1}{\Var*{ad}}&
	\bitbox{1}{\Var*{uspd}}&
	\bitbox{1}{\Var*{rspd}}&
	\bitbox{1}{\Var*{ad$_G$}}&
	\bitbox{1}{\z{\$}} &
	\bitbox{1}{\z{V}} \\
	\bitbox{2}{\Var*{hwversion}}
	\bitbox{1}{\z\$}&
	\bitbox{1}{\z{R}} &
	\bitbox{2}{\Var*{romversion}}&
	\bitbox{1}{\z{\$}}& 
	\bitbox{1}{\z{S}}& 
	\bitbox{1}{\Var*{serial}} \\
	\bitbox{1}{\z{\$}} &
	\bitbox{1}{\z{\textbackslash n}}
\end{bytefield}
\end{center}

The \Var*{model} field is ``\z{B}'' for the busylight hardware. Other codes
designate other compatible devices.

\Var*{hwversion} and \Var*{romversion} indicate the versions, respectively, of the 
hardware the firmware was compiled to drive, and of the firmware itself. Each of
these fields are variable-width and conform to the semantic version standard 2.0.0.\footnote{See
\href{https://semver.org}{semver.org}.} Each is terminated by a dollar-sign (\z\$) character (and
thus those strings may not contain dollar signs).

The \Var*{serial} field is a variable-width alphanumeric string which was set when the firm\-ware was
compiled. It should be a unique serial number for the device (although that depends on
some effort on the part of the person compiling the firmware to insert that serial number
each time). Serial numbers B000--B299 are reserved for the original author's use. This string is also
terminated with a dollar sign.

The \Var*{ad}, \Var*{uspd}, and \Var*{rspd} values are as last set by the \z= command (or the factory
defaults if they were never changed). If the serial device is disabled, ``\z{\_}'' is sent instead of
the baud rate code. Likewise, ``\z{\_}'' is sent for the address of a device for which no address
is set. ``\z{*}'' is sent for an address that is somehow invalid.

The status message sent to the host is terminated by a newline character (hex byte \z{0A}),
indicated in the protocol description above as ``\z{\textbackslash n}''.

\section{\z{S}---Light Single \led}
\begin{center}
\begin{bytefield}[endianness=little,bitwidth=0.11111\textwidth]{2}
	\bitheader{0-1} \\
	\bitbox{1}{\z{S}} &
	\bitbox{1}{\Var*{led}} 
\end{bytefield}
\end{center}

Stops the flasher (cancelling any previous \z{F} command) and turns off all discrete
\led s. The single \led\ indicated by \Var*{led} is turned on. See Table~\ref{tbl:lightcodes}. Note that if a strobe sequence is running (via a previous \z{*} command),
it remains running.

This command may be given in upper- or lower-case (``\z{s}'' or ``\z{S}'').

\section{\z{X}---Turn off Discrete \led s}
\begin{center}
\begin{bytefield}[endianness=little,bitwidth=0.11111\textwidth]{1}
	\bitheader{0} \\
	\bitbox{1}{\z{X}} 
\end{bytefield}
\end{center}

Turns off the flasher, strober, and all discrete \led s.

This command may be given in upper- or lower-case (``\z{x}'' or ``\z{X}'').

\input pinouts

\indexintoc

\printindex
\end{document}

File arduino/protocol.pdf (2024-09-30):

# Busylight

# User’s Guide

# WORKING

# DRAFT

ii

The information in this document, and the hardware and software it

describes, are hobbyist works created as an educational exercise and as a

matter of personal interest for recreational purposes.

It is not to be considered an industrial-grade or retail-worthy product.

It is assumed that the user has the necessary understanding and skill to

use it appropriately. The author makes NO representation as to suitability

or fitness for any purpose whatsoever, and disclaims any and all liability or

warranty to the full extent permitted by applicable law. It is explicitly not

designed for use where the safety of persons, animals, property, or anything

of real value depends on the correct operation of the software.

For busylight hardware version 1.0.2, and firmware version 2.0.0.

Copyright © 2023 by Steven L. Willoughby (aka MadScienceZone), Aloha,

Oregon, USA. All Rights Reserved. This document is released under the

terms and conditions of the Creative Commons “Attribution-NoDerivs 3.0

Unported” license. In summary, you are free to use, reproduce, and redis-

tribute this document provided you give full attribution to its author and

do not alter it or create derivative works from it. See

http://creativecommons.org/licenses/bynd/3.0/

for the full set of licensing terms.

# Contents

Contents | iii
List of Figures | iv
List of Tables | iv
1 | Protocol Description | 1
2 | Connector Pinouts | 9
| Full-Duplex RS-485 Connection (8p8c Female Modular Jacks) . | 9
| Half-Duplex RS-485 Connection (6p6c Female Modular Jacks) . | 9

## iii

# List of Figures

# List of Tables

1.1 | Summary of All Commands | | | 4
1.2 | Baud Rate Codes | | | 5
1.3 | ASCII Encoded Integer Values (0–63) | | 6
1.4 | Discrete LED Codes and Colors | | | 7

iv

# C h a p t e r

1

# Protocol Description

Protocol is etiquette with a government

expense account.

—Judith Martin
T

he protocol used to control the busylight device is very simple. Com-

mands are expressed largely in plain ASCII characters and are exe-

cuted immediately as they are received.1

# USB vs. RS-485

The protocol used to send commands to the busylight is different depending

on whether the host is sending directly to a single device over a USB cable,

or to (possibly) multiple devices over an RS-485 bus network.

This was designed for the Adruino Nano controller, which only has a

single USART, so the busylight will differentiate between USB and RS-485

commands from their respective formats. On other units with multiple

serial ports, one is dedidated to the RS-485 network.

## USB

A busylight connected via USB accepts the commands just as documented

below, with the addition that each such command is terminated by a ^D

byte (hex value 0416).

1Technically, they may even be executed while they are being received.

1

2 | Chapter 1. Protocol Description

0

. . . | n − 1 | n
⟨command⟩ | | ^D

If there is an error parsing or executing a command, the busylight will

ignore all subsequent input until a ^D is received, whereupon it will ex-

pect to see the start of another command. Thus, ^D may not appear in any

transmitted data except to terminate commands.

RS-485

Commands sent over RS-485 are intended to target one or more of a set

of connected busylight units over a network which may also contain other

Lumos-protocol-compatible devices, so they use a protocol compatible with

that use case.

Each command begins with one of the following binary headers, depend-

ing on the set of target busylight units which should obey the command.

Single Target or All Devices

To send a command to a single unit, begin with a single byte encoded as:

01234567
1 | 0 0 1 | ⟨ad⟩

where ⟨ad⟩ is the unit’s address on the bus, which must be a value in the

range 0–15. This byte is followed by any command as described below. If

the global address adG is given as the ⟨ad⟩ value, then all busylight units

which have that set as their global address will obey the command.

## Multiple Targets

Alternatively, a command may be targetted to multiple units by starting

the command with a multi-byte code:

01234567
1 | 0 1 1 | ⟨adG⟩
0 | 0 | ⟨n⟩
0 | 0 | ⟨ad0⟩
0 | 0 | ⟨adn−1⟩

where ⟨adG⟩ is the “global” device address which signals busylight units

generally (see the = command below). This will send to the ⟨n⟩ devices

addressed as ⟨ad0⟩ through ⟨adn−1⟩.

Note that the address of a unit is constrained to four bits (values 0–15) in

the regular command header, but the address values listed here are seven

Command Summary | 3

bits wide (values 0–63). This allows you to give busylight devices address

above 15, but if you do this, then this multiple-target header must be used

to send commands to them, since their addresses won’t fit in the shorter

single-byte header.

## All Off

As a special case, the single byte

01234567
1 | 0 0 0 | ⟨ad⟩

will cause the busylight addressed as ⟨ad⟩ to turn off all LEDs. If ⟨ad⟩ is the

adG address, then all busylight units will turn off all LEDs.

No other command bytes need to follow; this byte is sufficient to turn off

the unit(s).

Subsequent Command Bytes

All subsequent bytes which follow the above binary headers must have their

MSB cleared to 0.

To cover cases where a value sent as part of a command must have the

MSB set, we use the following escape codes:

- A hex byte 7E16 causes the next byte received to have its MSB set upon

receipt.

- A hex byte 7F16 causes the next byte to be accepted without any fur-

ther interpretation.

Thus, the byte C416 is sent as the two-byte sequence 7E 44, while a literal

7E is sent as 7F 7E and a literal 7F as 7F 7F.

If there is an error parsing or executing a command, the busylight will

ignore all subsequent input until a byte arrives with its MSB set to 1, where-

upon it will expect to see the start of another command.

### Command Summary

### *—Strobe Lights in Sequence

0 | 1 | 2 | 3 | . . . | n | n + 1
* | ⟨led0⟩ ⟨led1⟩ ⟨led2⟩ | · · · | ⟨ledn−1⟩ | $

Each ⟨led⟩ value is an ASCII character corresponding to a discrete LED as

shown in Table 1.4. An ⟨led⟩ value of “_” means there is no LED illuminated

at that point in the sequence.

4 | Chapter 1. Protocol Description
Command | Description | Notes
? | Query discrete LED status | [1] [2]
= | Set operational parameters | [2]
* | Strobe LEDs in Sequence
F | Flash LEDs in Sequence
L | Light one or more LEDs steady
Q | Query device status | [1] [2]
S | Light one LED steady
X | All LEDs off
[1] Sends response
[2] USB only

Table 1.1: Summary of All Commands

This command functions identically to the F command (see below), ex-

cept that the lights are “strobed” (flashed very briefly with a pause between

each light in the sequence).

### =—Set Operational Parameters

0 | 1 | 2 | 3 | 4
= | ⟨ad⟩ | ⟨uspd⟩ | ⟨rspd⟩ | ⟨adG⟩

This command sets a few operational parameters for the unit. Once set,

these will be persistent across power cycles and reboots.

If the ⟨ad⟩ parameter is “_” then the RS-485 interface is disabled en-

tirely. Otherwise it is a value from 0–63 encoded as described in Table 1.3.

This enables the RS-485 interface and assigns this unit’s address to ⟨ad⟩.

Note that if you assign an address greater than 15 you can only address

the unit via multiple-target headers or via the global address.

The baud rate for the USB and RS-485 interfaces is set by the ⟨uspd⟩ and

⟨rspd⟩ values respectively. Each is encoded as per Table 1.2.

The ⟨adG⟩ value is an address in the range 0–15 which is not assigned

to any other device on the RS-485 network. This is used to signal that all

busylight units should pay attention to the start of the command because

it might target them either as part of a list of specific busylight units or

because the command is intended for all busylight units at once. This is

encoded in the same way as ⟨ad⟩. If you only have one busylight or do no

wish to assign a global address, just set ⟨adG⟩ to the same value as ⟨ad⟩.

This command may only be sent over the USB port.

By default, an unconfigured busylight is set to 9,600 baud with the RS-

485 port disabled.

?—Query Discrete LED Status | 5
Code | Speed
0 | 300
1 | 600
2 | 1,200
3 | 2,400
4 | 4,800
5 | 9,600 | (default)
6 | 14,400
7 | 19,200
8 | 28,800
9 | 31,250
A | 38,400
B | 57,600
C | 115,200

Table 1.2: Baud Rate Codes

### ?—Query Discrete LED Status

0
?

This command causes the unit to send a status report back to the host

to indicate what the discrete LEDs are currently showing. This response

has the form:

0 | 1 | 2 | 3 | 4 | 5 | 6 | 7 | 8
L | ⟨led0⟩ ⟨led1⟩ ⟨led2⟩ ⟨led3⟩ ⟨led4⟩ ⟨led5⟩ · · · ⟨ledn−1⟩
$ | F | flasher status (see below)
$ | S | strober status (see below)
$ | \n

Each ⟨ledx⟩ value is a single character which is “_” if the corresponding

LED is off, or the LED’s color code or position number if it is on. a “?” is sent

if the value set for the LED is invalid. One such value is sent for each LED

installed in the unit (typically seven for busylight units), followed by a “$”

to mark the end of the list.

The flasher and strober status values are variable-width fields which

indicate the state of the flasher (see F command) and strober (see * com-

mand) functions. In each case, if there is no defined sequence, the status

## field will be:

6 | Chapter 1. Protocol Description
Value | Code | Value | Code
0–9 | 0–9 | 17–42 | A–Z
10 | : | 43 | [
11 | ; | 44 | \
12 | < | 45 | ]
13 | = | 46 | ^
14 | > | 47 | _
15 | ? | 48 | ‘
16 | @ | 49–63 | a–o

(Each code is the numeric value plus 48.)

Table 1.3: ASCII Encoded Integer Values (0–63)

0 | 1
⟨run⟩ | _

Otherwise, the state of the flasher or strober unit is indicated by:

0 | 1 | 2 | 3 | 4 | . . . | n + 3
⟨run⟩ | ⟨pos⟩ | @ | ⟨led0⟩ ⟨led1⟩ | · · · | ⟨ledn−1⟩

In either case, ⟨run⟩ is the ASCII character “S” if the unit is stopped or “R”

if it is currently running. If there is a defined sequence, ⟨pos⟩ indicates the

0-origin position within the sequence of the light currently being flashed or

strobed, encoded as described in Table 1.3. The ⟨ledx⟩ values are as allowed

for the F or * command that set the sequence. (Regardless of the actual F

or * command parameters, the report will show symbolic color codes where

possible, or numeric position codes otherwise.)

The status message sent to the host is terminated by a newline charac-

ter (hex byte 0A), indicated in the protocol description above as “\n”.

This command may only be sent on the USB port.

### F—Flash Lights in Sequence

0 | 1 | 2 | 3 | . . . | n | n + 1
F | ⟨led0⟩ ⟨led1⟩ ⟨led2⟩ | · · · | ⟨ledn−1⟩ | $

Each ⟨led⟩ value is an ASCII character corresponding to a discrete LED

as shown in Table 1.4. Note that the assignment of colors to these LEDs is

dependent on your particular hardware being assembled that way. As an

open source project, of course, you (or whomever assembled the unit) may

choose any color scheme you like when building the board.

Q—Query Device Status | 7
Code* | Light | Color
B | L0 | blue
R | L1 | red
r | L2 | red
Y | L3 | yellow
G | L4 | green
_ | — | (no LED/off)
0–9 | L0⁻L9 | LED installed at physical position 0–9

*If a unit is built with different colors in these positions, the letter codes

for those LEDs will match the custom color arrangement for that unit.

Table 1.4: Discrete LED Codes and Colors

An ⟨led⟩ value of “_” means there is to be no LED illuminated at the

corresponding position in the sequence.

Up to 64 ⟨led⟩ codes may be listed. The unit will cycle through the se-

quence, lighting each specified LED briefly before moving on to the next

one. The sequence is repeated forever in a loop until an L, S or X command

is received.

If only one ⟨led⟩ is specified, that light will be flashed on and off. Setting

an empty sequence (no codes at all) stops the flasher’s operation.

The sequence is terminated by either a dollar-sign (“$”) character or the

escape control character (hex byte 1B), indicated in the protocol diagram

above simply as “$”.

This command may be given in upper- or lower-case (“f” or “F”).

### Q—Query Device Status

0
Q

This command causes the unit to send a status report back to the host to

indicate the general status of the device except for the discrete LED display

which may be queried using the ? command. The response has the form:

0 | 1 | 2 | 3 | 4 | 5 | 6 | 7 | 8
Q | ⟨model⟩ | = | ⟨ad⟩ | ⟨uspd⟩ | ⟨rspd⟩ | ⟨adG⟩ | $ | V
⟨hwversion⟩ | | $ | R | ⟨romversion⟩ | | $ | S | ⟨serial⟩
$ | \n

8 | Chapter 1. Protocol Description

The ⟨model⟩ field is “B” for the busylight hardware. Other codes desig-

nate other compatible devices.

⟨hwversion⟩ and ⟨romversion⟩ indicate the versions, respectively, of the

hardware the firmware was compiled to drive, and of the firmware itself.

Each of these fields are variable-width and conform to the semantic version

standard 2.0.0.2 Each is terminated by a dollar-sign ($) character (and thus

those strings may not contain dollar signs).

The ⟨serial⟩ field is a variable-width alphanumeric string which was set

when the firmware was compiled. It should be a unique serial number for

the device (although that depends on some effort on the part of the per-

son compiling the firmware to insert that serial number each time). Serial

numbers B000–B299 are reserved for the original author’s use. This string

is also terminated with a dollar sign.

The ⟨ad⟩, ⟨uspd⟩, and ⟨rspd⟩ values are as last set by the = command

(or the factory defaults if they were never changed). If the serial device is

disabled, “_” is sent instead of the baud rate code. Likewise, “_” is sent for

the address of a device for which no address is set. “*” is sent for an address

that is somehow invalid.

The status message sent to the host is terminated by a newline charac-

ter (hex byte 0A), indicated in the protocol description above as “\n”.

# S—Light Single LED

0 | 1
S | ⟨led⟩

Stops the flasher (cancelling any previous F command) and turns off all

discrete LEDs. The single LED indicated by ⟨led⟩ is turned on. See Table 1.4.

Note that if a strobe sequence is running (via a previous * command), it

remains running.

This command may be given in upper- or lower-case (“s” or “S”).

### X—Turn off Discrete LEDs

0
X

Turns off the flasher, strober, and all discrete LEDs.

This command may be given in upper- or lower-case (“x” or “X”).

2See semver.org.

# C h a p t e r

2

# Connector Pinouts

### Full-Duplex RS-485 Connection (8p8c Female Modular

### Jacks)

1 | 8

1 Return Data (+) (W/Or)

2 Return Data (−) (Or)

## 3 Cable Check (W/Gr)

## 4 Data (−) (Bl) 5 Data (+) (W/Bl)

## 6 Cable Check (Gr)

7 Data Ground (W/Br)

8 Return Data Ground (Br)

### Half-Duplex RS-485 Connection (6p6c Female Modular

### Jacks)

1 | 6

## 1 Cable Check (W/Gn)

2 Data Ground (W/Br)

## 3 Data (−) (Bl) 4 Data (+) (W/Bl)

5 Data Ground (Br)

## 6 Cable Check (Gn)

9

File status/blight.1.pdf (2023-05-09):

BLIGHT(1) | User Commands | BLIGHT(1)

NAME
blight − GUI frontend to busylight SYNOPSIS
[wish8.6] blight.tcl
DESCRIPTION
The blight.tcl script is a simple GUI front-end to the busylight(1) program. It provides an on-screen indication of the light status (helpful if you can’tphysically see the LEDs) and a row of buttons to click on to easily change the light status.

All of its operations are carried out by running the busylight program to do the work.

Every 5 minutes, it will query the state of the lights and update its on-screen indicator accordingly,but it will also do this when you manually change the status or click the refresh button.

Buttons are provided for each of the defined status values in your ˜/.busylight/config.json file (except the start and stop statuses), as well as a series of buttons labelled servermute, serveropen,etc., which allow you to set the daemon’sstate.
ACTIVITIES
Blight adds another feature not otherwise provided by busylight.Itallows for activity tracking. Touse this feature, you will need to create a file called ˜/.busylight/activities.json which contains a JSON array of objects, each of which has the following fields:
Name | This should be a short (preferably one-word) name of the activity to be tracked.
Status | This is a JSON array of string values. Each value is a set of arguments to busylight to set the lights appropriately for this activity.The words in the string value will be added to the command line; if more than one string is given, busylight will be invokedonce for each string.
Elapsed | An integer value giving the number of minutes spent so far on that activity.

An example activities.json file might look likethis:

[
{"Name":"Meetings", "Status":["-open"], "Elapsed":0}, {"Name":"Idle", "Status":["-status idle"], "Elapsed":12}, {"Name":"Games", "Status":["-status busy","-status lowpri"],
"Elapsed":120}
]

The blight script will update this file with new Elapsed values while activities are active.

To start an activity,click on its button. That will set the lights for the activity and start the timer to track time for that activity.Clicking other buttons will change lights but not change the running timer.Clicking another activity will stop the current one before starting the newactivity.Clicking the (stop activity) button will stop the activity timer without starting a newone.
AUTHOR
Steve Willoughby <steve@madscience.zone>
09-May-2023 | 1.9.1 | 1

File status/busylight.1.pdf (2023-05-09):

BUSYLIGHT(1) | User Commands | BUSYLIGHT(1)

NAME
busylight − display busy/free status to passers-by
SYNOPSIS
busylight [−cal][−help][−kill][−list][−mute][−open][−query][−raw command][−reload][−status name][−wake][−zzz]

busylightd

upcoming
OPTIONS
Each command that accepts command-line options is described below. Note that option names may be preceded by one or twohyphens (e.g., either −−mute or −mute), but options may not be abbreviated or combined.
busylight
The busylight command manually sets the status display on the light device. If a daemon is running, it will attempt to notify the daemon for those states which it’salso tracking (−cal, −mute,and −open), or for commands which directly manipulate the daemon itself (−kill, −reload, −wake,and −zzz).

The options recognized include the following:
−cal | Tell the daemon to return to reporting state based on calendar availability.(This signals
that a call has ended.)
−help | Summarize the command-line options and exit.
−kill | Tell the daemon to terminate immediately.
−list | List all the status codes usable with the −status option and then exit.
−mute | Tell the daemon that we are in a call with the microphone muted.
−open | Tell the daemon that we are in a call with the microphone open.
−query | Queries the hardware state and reports it to the user.

−raw command Send the command string as-is to the light controller device. See below.

−reload | Force the daemon to re-poll the calendar service to get updates to the schedule rather than
| waiting for the next periodic poll time.
−status name | Set the light tree device to the status light pattern defined for the given name in the config-
| uration file (does not notify the daemon).
−wake | Tell the daemon to come on line if it was sleeping. The Google calendars are polled and
| resulting status is displayed by the daemon.
−zzz | Tells the daemon to go to sleep; turns offthe signal light and stops polling the calendar
service.
DESCRIPTION
The tools described here control a hardware status signal attached to the computer’sUSB port. This is a custom hardware device which employs a simple serial protocol and is not necessarily compatible with anything else.
The normal course of operations is to start up the status monitor daemon, busylightd, in the background. This will poll the user’sGoogle calendar(s) to see when theyare busy or free, and will continue to poll every hour to keep up with changing schedules throughout the day.

The daemon also monitors the state of a video conferencing meeting such as Zoom, to arrange a set of signals to anyone in visual range of the light, such as:

green | Currently free, and able to be approached/interrupted at will.
yellow | Marked busy on a calendar,and thus may be working on something less
| amenable to interruption.
09-May-2023 | 1.9.1 | 1

red | Actually joined a conference call via Zoom, etc., so should not be inter-
rupted (and possibly on-camera so anyone who comes in camera range may be visible to meeting participants).
flashing red | In a conference call and the microphone is open, so anynearby sounds may
be heard by all meeting participants.

The actual monitoring of video meetings and microphone statuses is assumed to be done by some other automation which signals the daemon by sending signals to its process or running the busylight CLI tool. The author uses a hammerspoon script to accomplish this.

See the SIGNALS section belowfor a description of howsending signals to the daemon affect its operation. The busylight CLI program is a convenient way to inform the daemon of a status change as an alternative tosending signals directly to the daemon. It is also used to directly send commands to the light control device regardless of whether the daemon is running or not.
The upcoming program polls the Google calendars and displays to standard output the busy/free time ranges for the next 8 hours.
CONFIGURATION
These tools require a fewfiles to be placed in the user’s ˜/.busylight directory.The overall tool configuration will be in a file called config.json in that directory.

This file provides all of the configuration parameters needed for the ongoing operation of the system. As the name implies, it is in JSON format, as a single object with the following fields:
Colors
This is a string containing single-character names for each of the LEDs as implemented on your particular hardware device. For example, a light with three LEDs—red, yellow, and green—with red in position #0 might be represented by a value of "RYG".These are used for reporting device status via the −query option.

ColorValues
This is an object mapping color letters as listed in the Colors field to actual color names or #rrggbb values as accepted by tk.
StatusLights
This is a map which defines a symbolic name for each signal pattern you wish to display.You are not limited to only these patterns, but the advantage is that you may refer to them by the defined names rather than the rawcodes. The following names are needed by busylightd (although defaults will be used if theyare not defined here in the config file):
busy | Signals that you are busy (per your calendar events). Defaults to “S3”.
free | Signals that you are free (per your calendar events). Defaults to “S4”.

muted Signals that you are in a meeting with your microphone muted. Defaults to “S2”.

off | Turns offall lights. Defaults to “X”.
open | Signals that you are in a meeting with your microphone open. Defaults to “F12$”.
start | Flashed twice rapidly when the daemon starts up or wakes. Defaults to “S0”.
stop | Flashed twice rapidly when the daemon stops or sleeps. Defaults to “S1”.

In each case, the rawcodes used to display light patterns may include anycombination of the following:
Fn...$ Flash one or more lights in sequence. If a single value is givenfor n,that light is flashed. If multiple light numbers are given(e.g., “F12$”) theyare sequenced in a repeating cycle. Sequences of up to 64 elements are accepted. The “$”terminator may be an ASCII ESC character or a dollar sign.
Sn | Turn on light #n.Only one of these may be on at once, and this is mutually exclusive with F.
09-May-2023 | 1.9.1 | 2

*n...$ Strobe one or more lights in sequence. This may be combined with other effects. The light(s) indicated are very briefly flashed, with a longer pause between each flash. If there are no lights listed at all, this cancels the strobe effect. The terminator is as described above.Se- quences of up to 64 elements are supported.

X Turn offall lights.

Calendars
This is a map of Google calendar IDs to objects which describe those calendars. The data associated with each key is an object with the following fields:
Title
An arbitrary name for the calendar that will explain its purpose.
IgnoreAllDayEvents
Aboolean value; if true, busylightd will ignore anybusy periods for that calendar which span the entire 8-hour period being queried. Defaults to false.
The key "primary" may be used in place of the Google ID to refer to the user’sprimary calendar.

TokenFile
The name of a file in which the program can cache authentication tokens to allow it tocontinue polling Google calendars. This should be a filename in the .busylight directory with restricted permissions to avoid unauthorized viewing.
CredentialFile
The name of a JSON file containing the API access credentials obtained from Google.
LogFile
The name of a file into which busylightd should record a log of its activities.

PidFile
The name of the file busylightd should use to indicate its PID while running.

Device
The system device name of the busylight signal hardware.
DeviceDir
If Device is omitted or blank, then a suitable device will be searched for in the directory named here. See also DeviceRegexp.

DeviceRegexp
If searching for a device name in DeviceDir,the first device whose name matches the regular expression givenhere and can be successfully opened as a serial port will be used.
BaudRate
The speed the hardware expects to be used to communicate with it.

An example configuration file would look likethis:
{
| "Colors": "BrRYG", "ColorValues": { "B": "blue", "R": "red", "r": "red", "Y": "yellow", "G": "green"

},
| "StatusLights": { "busy": "S3", "free": "S4", "urgent": "F01$"

},

09-May-2023 | 1.9.1 | 3

"Calendars": {
"primary": {
"Title": "My primary calendar"
},
"mycustomcalendar@group.calendar.google.com": { "Title": "Group calendar",
"IgnoreAllDayEvents": true
}
},
"TokenFile": "/Users/MYNAME/.busylight/auth.json", "CredentialFile": "/Users/MYNAME/.busylight/credentials.json", "LogFile": "/Users/MYNAME/.busylight/busylightd.log", "PidFile": "/Users/MYNAME/.busylight/busylightd.pid", "Device": "/dev/tty.usbmodem2101",
"BaudRate": 9600
}
If using a regular expression for the device rather than a fixed name, the Device entry of the above JSON might be replaced with these two:
"DeviceDir": "/dev",
"DeviceRegexp": "ˆtty\\.usbmodem\\d+$", AUTHENTICATING
In order to use the daemon to query Google calendar busy/free times, you first need to obtain an API key from Google. This will go in your ˜/.busylight/credentials.json file (or whateveryou named it in ˜/.busylight/config.json). An example of this file is:
{
"installed" : {
"client_id": "...",
"project_id": "...",
"auth_uri": "https://accounts.google.com/o/oauth2/auth",
"token_uri": "https://oauth2.googleapis.com/token","auth_provider_x509_cert_url": "https://www.googleapis.com/oauth2/v1/certs","client_secret":"...",
"redirect_uris": ["urn:ietf:wg:oauth:2.0:oob","http://localhost"]
}
}

Next, you will need to manually authenticate to Google once before the daemon can continue to poll the calendar API on its own. To do this, run the upcoming program. If you already have valid access tokens cached, it will simply report your busy/free times for the next 8 hours. Otherwise, it will print a lengthy URL on its standard output and wait for your response.

Copythat URL into a web browser.This will takeyou to Google where it will ask you to log in to the Google account whose calendars you wish to have monitored. You will also be asked if you are sure you want to give permissions to the app to have acceess to all of your calendars. If you agree, Google will give you an access token string.
Copythat string and paste it into the terminal where you are running upcoming so it is sent to upcoming’s standard input and press the return key.
This will authorize the client to access the calendar API, so upcoming will then print out its report of your upcoming appointment times. But in doing so it will also have cached your authentication token in the ˜/.busylight/auth.json file (or whateveryou named it in config.json), so the programs documented here may freely poll the calendar service using that token.
If the busylight tools suddenly stop being able to access the calendar,simply delete the auth.json file and repeat this process to get a newtoken cached.
09-May-2023 | 1.9.1 | 4

Security Implications
Protect the data in the auth.json file carefully.Any program with access to that data will have full rights to viewand modify your Google calendars.

When you no longer wish to authorize these tools to access your calendars, you may go into your Google account settings on Google’swebsite to revoke that authorization.
SIGNALS
The busylightd daemon responds to the following signals:
HUP | The video conference call is over. The daemon changes the light signal to reflect the user’s busy/free status as understood from the last poll of the Google calendars.
INFO | The daemon will immediately poll the calendar API instead of waiting for the next scheduled poll time. This is useful if a last-minute change was made to the calendar.This does not other- wise alter the periodic polling schedule (e.g., if the daemon is polling at 5 minutes past each hour,and this signal is received at 3:45, the next poll will still takeplace at 4:05).
INT | Upon receipt of this signal, the daemon gracefully shuts down and terminates.

VTALRM Instructs the daemon to wake up from sleep state. The daemon will immediately poll the cal-
| endar service, and will then poll again an hour after that, and every hour thereafter.
| When resuming active status after having been inactive,the daemon will reload the configura- tion file. This provides a convenient way to change configuration options by suspending opera- tions and then resuming, without needing to completely restart the daemon. The PID and log files may not be changed without restarting the daemon completely.Also note that the API cre- dentials for accessing Google calendars is not reloaded at this time. That also requires a full restart of the daemon process.
USR1 | The user is in a video conference with the microphone muted. The light signal is changed to re- flect this.
USR2 | The user is in a video conference with the microphone open. The light signal is changed to re- flect this.
WINCH | Put the daemon to sleep. This is usually used to mark the end of the workday.The light signal is shut offcompletely and the daemon stops polling the calendar service.

AUTHOR
Steve Willoughby <steve@madscience.zone>
PORTABILITY
The author’sintended use for the daemon was on a Macintosh osx system, and the choice of signals was based on their availability on that platform. Other operating systems may not support all of those signals, so porting to those systems may involveadifferent selection of signals.
09-May-2023 | 1.9.1 | 5

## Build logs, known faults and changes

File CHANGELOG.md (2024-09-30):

# Archived
This project has now been archived and its development is now taking place as part of
the [Readerboard project](https://github.com/MadScienceZone/readerboard), which is a superset
of this one.

## Version 1.10.0
### Blight changes
 * Added "Clear times" button and improved support for tracking activity times.
 * Introduced 1 second delay before updating display to allow time for the light device to complete what it was supposed to do. 

## Version 1.9.1
Improved blight script, also added `ColorValues` field to `config.json`.

## Version 1.9.0
Added a simple GUI front-end which provides buttons to change status on the lights as well
as simple time tracking of activities.

## Version 1.8.2
Added an output line to the `-query` option to indicate whether the daemon is
currently running or not.

## Version 1.8.1
Added the ability to name the light colors for a more human-friendly output
from the `-query` option.

## Version 1.8
Added a `-query` option to `busylight` and corresponding firmware support to allow
the user to ask the hardware which lights are on and what sequences are playing.

## Version 1.7
Added a `-list` option to `busylight` which lists out all the defined status codes
(from the configuration file) that the user can specify with the `-status` option.

## Version 1.6.1
Made a slight change to the order in which `busylight` sends commands to the daemon,
so that `-wake` happens first in the sequence and `-zzz` happens last.

## Version 1.6
Colors are now arbitrary and up to 7 lights are supported. New shield PCB introduced.
New protocol introduced to support more arbitrary light patterns.

Removed superfluous `busylight-standalone` command. Now both `busylight` and `busylightd` can
directly update the device since as of this version neither leaves the I/O
port open all the time. In case of a collision, the programs will wait for the other to
let go of the port before proceeding.

## Version 1.5
Adds a low-priority indicator to be added in addition to the other
markers so you can say things like "I'm in a video call but it's not
so important that I can't be interrupted. Just understand I'm on camera."

Also re-added the 1.4 changes to the repo since apparently they didn't get
committed correctly before.

Also also becoming very apparent that using signals to notify the daemon
of changes in state was a bad idea (given the limited availability of
signals that are safe to co-opt for this usage), so a future version will 
likely introduce a new mechanism for that.

## Version 1.4
Allows a regular expression for the device name now, so that the daemon
can search for whatever name the OS randomly chose for the hardware device.

## Version 1.3
The daemon now closes the serial port when put in inactive state and
re-opens it when going active again. It also reloads its configuration
file at that time, making it possible to change the serial device in case
the system gave it a new dynamic device name during the time the daemon
was sleeping.

This also allows other configuration changes to be made  without restarting
the daemon (just set it to inactive state and back to active again).

Refactored some code to clean it up a little. 

## Version 1.2
The 1.2 release includes the ability to ignore long-running appointments on selected calendars, to avoid
signalling that the user is "busy" because of an all-day event on a group calendar.

This made it necessary to change the `config.json` file's list of calendars to be monitored. Users of the 1.1 version will need to 
update this configuration file after upgrading to 1.2.

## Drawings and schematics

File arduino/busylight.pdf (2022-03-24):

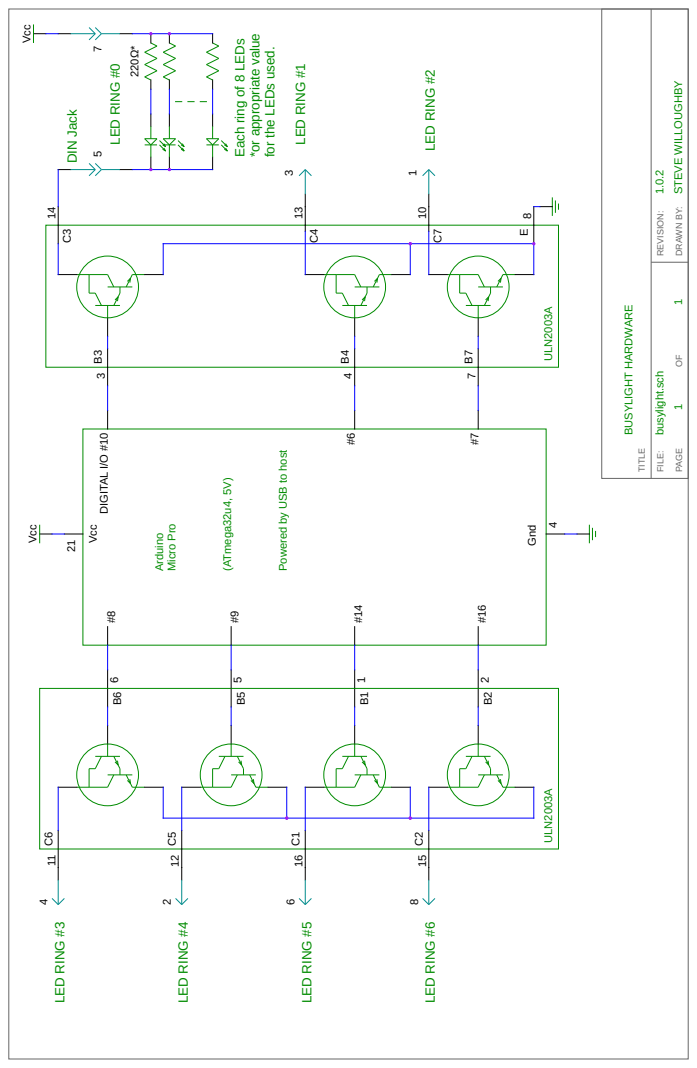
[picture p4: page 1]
FILE: REVISION:; DRAWN BY:; TITLE; PAGE OF; Arduino; Micro Pro; Vcc; (ATmega32u4, 5V); DIGITAL I/O #10; Gnd; ULN2003A; BUSYLIGHT HARDWARE; busylight.sch; STEVE WILLOUGHBY; DIN Jack; LED RING #0; LED RING #1; LED RING #2; LED RING #3; LED RING #4; LED RING #5; LED RING #6

*or appropriate value

Each ring of 8 LEDs

for the LEDs used.

Powered by USB to host

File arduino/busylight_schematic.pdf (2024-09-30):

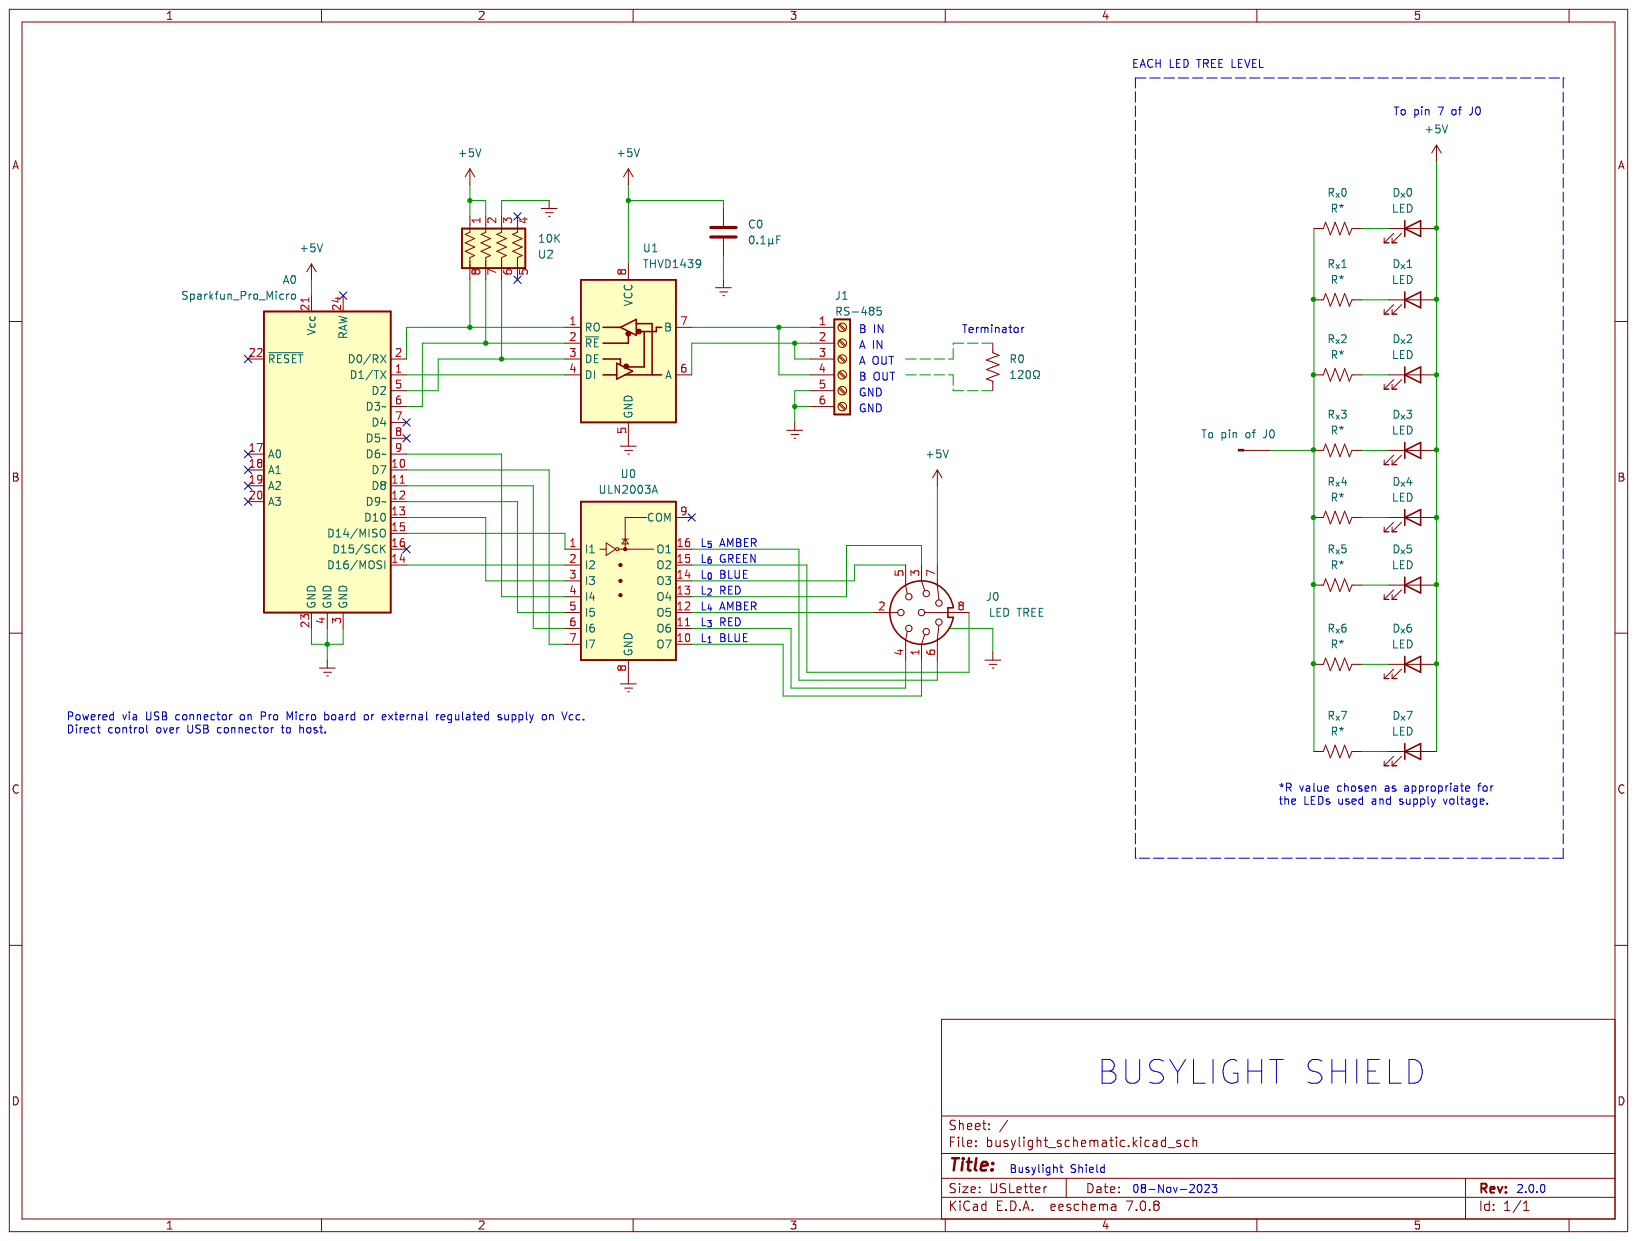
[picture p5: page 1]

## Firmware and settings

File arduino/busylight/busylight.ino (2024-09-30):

//  ____  _   _ ______   ___     ___ ____ _   _ _____   v2.0.0 firmware
// | __ )| | | / ___\ \ / / |   |_ _/ ___| | | |_   _| 
// |  _ \| | | \___ \\ V /| |    | | |  _| |_| | | |  
// | |_) | |_| |___) || | | |___ | | |_| |  _  | | |  
// |____/ \___/|____/ |_| |_____|___\____|_| |_| |_|  
//
// THIS FIRMWARE IS FOR A PRO MICRO CONTROLLER ATTACHED
// TO A BUSYLIGHT VERSION 2 SHIELD. If you are using a version 1
// shield, it should still work, but since that board does not
// have an RS-485 port, those functions will simply not work.
//
// The Pro Micro (often called the SparkFun Pro Micro, and made by a variety
// of different manufacturers) is based on the ATmeta32U4 
// (we use the 5V, 16MHz version).
//
// In the Arduino IDE, set the board type to "SparkFun Pro Micro",
// The CPU type to "ATmega32U4 (5V, 16 MHz)".
// You may need to add support for this to your board manager by adding
// https://raw.githubusercontent.com/sparkfun/Arduino_Boards/main/IDE_Board_Manager/package_sparkfun_index.json
// to your IDE's preferences.
//
// ===> CHANGE THE FOLLOWING PER DEVICE before flashing. <===
//
// THIS_DEVICE_COLOR_MAP can be empty or contain letter
// codes to represent the colors implemented in light
// positions 0-6. Any left off at the end of the list
// must be addressed only by position numbers in the
// protocol commands.
#define THIS_DEVICE_COLOR_MAP "BRrYG"
//                             ^^^^^^^
//                             0123456
//
// SERIAL_VERSION_STAMP holds the version number of your
// hardware, the version of this firmware code, and the
// unique serial number for this unit. Serial numbers
// B000-B299 are reserved for the author; please use other
// values for your own devices. Serial numbers must be alphanumeric only.
#define SERIAL_VERSION_STAMP "V2.0.0$R2.0.0$SBXXX$"
//                             \___/  \___/  \__/
//                               |      |      |
//                  Hardware version    |      |
//                         Firmware version    |
//                                 Serial number
//
// These are variable-length values, each terminated by a dollar-sign ($).

/*
** Steve Willoughby <steve@madscience.zone>
** Licensing: BSD 3-clause open-source license
**
** Simple busylight indicator, controlled via USB serial commands.
** To use, open the USB device as a serial port and send commands to it. 
**
** The physical LED tree is stacked like so:
** The colors are suggested but they can be arbitrary.
**
**                  BLUE   B  ==================	#0
**                                    ||
**                  RED 2  R  ==================	#1
**                                    ||
**                  RED 1  r  ==================	#2
**                                    ||
**                  YELLOW Y  ==================	#3
**                                    ||
**                  GREEN  G  ==================	#4
**                                    ||
**                            ==================	#5
**                                    ||
**                            ==================	#6
**                                    ||
**                                    ||
**                                    ||
**                                    ||
**                                    ||
**
** PROTOCOL V2
** Legacy commands from V1 no longer supported.
**
** Commands may be received over the USB connection from a host computer,
** or over an RS-485 serial network.
**
** USB
** All commands received on the USB port are terminated with a ^D ($04) 
** byte. If an error occurs, all data are ignored until a ^D is received.
** Extra data after a command (but before the terminating ^D) is ignored.
**
** RS-485
** Commands received via RS-485 start with a binary
** header to be compatible with Lumos devices on the same network.
**
** 1000aaaa                                              turn all LEDs off. [1]
** 1001aaaa <command>                                    do <command> as described below. [1][3]
** 1011aaaa 0000nnnn 0000xxxx ... 0000xxxx <command>     do <command> as described below. [2][3]
**                   \________<n>________/
**
** [1] if aaaa is the device address or the global address, the unit will
**     respond to the command.
**
** [2] aaaa must be the global address; if the unit address is in the
**     list of addresses following the start byte, it will respond.
**
** [3] All following bytes must have MSB=0 and use the escape sequences:
**       01111110 0xxxxxxx     -> 1xxxxxxx (set MSB in next byte)
**       01111111 0xxxxxxx     -> 0xxxxxxx (take next byte literally)
**
** * <L0> <L1> ... <Ln-1> $     strobe LEDs
** = __ <spd>                   set baud rate to <spd>
** ?                            query LED status
** F <L0> <L1> ... <Ln-1> $     flash lights in sequence
** Q                            query device status
** S <L0>                       light single LED steady
** X                            turn off LEDs
**
** <Ln> - ASCII digit '0'..'6'.
** <spd> - 0=300 1=600 2=1200 3=2400 4=4800 5=9600* 6=14.4k 7=19.2k 8=28.8k 9=31.25k A=38.4k B=57.6k C=115.2k
** *default
**
** State Machine
**     -> ERR       signal error condition and go to ERROR state
**     -> END       go to END state
**     +            change transition and then re-examine current input byte
**                          
**                    
**                                                                             ____ 
**          $8a/$8g (485) _      $Bg (485)        _________  N    ____________|_   | Ad[0]-Ad[N-2]
**                       | |  +----------------->|Collect N|---->|CollectAddress|<-+
**        MSB=1 (485)+   | |  |                  |_________|     |______________|
**  _____  ^D (USB)     _|_V__|_   $9a/$Dg (485)  _____             |Ad[N-1]
** |ERROR|----------->||Idle    ||-------------->|Start|<-----------+
** |_____|<-----------||________||               |_____|
**   ^ |       *            |                        |
**   |_|*                   |<-----------------------+     _ 
**          ?/Q             |            ____             | |*
**  END <-------------------+ '*'   ____|_   | led       _V_|_  ^D
**                          +----->|Strobe|<-+      $   |END  |-----------> Idle
**   _____    =             |      |______|------------>|_____|
**  |Set  |<----------------+ 
**  |_____|                 |
**    | Ad/_                |
**   _V_____                |
**  |SetUspd|               |
**  |_______|               |
**    | speed               |
**   _V_____                |           ____
**  |SetRspd|               |  F    ___|_   |led
**  |_______|               +----->|Flash|<-+      $
**    | speed               |      |_____|----------> END 
**   _V_____                |  S    ________ led
**  |SetAg  |               +----->|LightSet|----------> END
**  |_______|               |      |________| 
**    | addr                |  X
**    V                     +-----> END
**   END
**
** Responses:
** ?
**     L <L0> <l1> ... <L6> $ F <flasher-status> $ S <strober-status> $ \n
**        <*-status> ::= <running?> _             (no sequence)
**                     | <running?> <pos> @ (<colorcode>|<digit>)*
**        <running?> ::= R=running | S=stopped
**        <pos> ::= encoded position value 0-63 as 0-9:;<=>?@A-Z[\]^_`a-o (numeric value+48)
**        <Ln> ::= <colorcode>|<digit>|_ (off)|? (out of range)
**
** Q
**     Q B = <address> <usb-speed> <rs-485-speed> <global-address> $ V <hwversion> $ R <romversion> $ S <serialno> $ \n
**
*/

#include <TimerEvent.h>
#include <EEPROM.h>

#define COUNTOF(X) (sizeof(X)/sizeof(X[0]))

//
// EEPROM locations
// $00 0x4B
// $01 baud rate code (USB)
// $02 baud rate code (RS-485 if on separate USART) or 0 if port disabled
// $03 unit address or UNIT_DISABLED
// $04 global address or UNIT_DISABLED
//
#define EE_ADDR_SENTINEL  (0x00) /* EEPROM $00: constant sentinel byte */
#define EE_ADDR_USB_SPEED (0x01) /* EEPROM $01: usb baud rate code */
#define EE_ADDR_485_SPEED (0x02) /* EEPROM $02: rs-485 baud rate code; NOT USED if common serial port */
#define EE_ADDR_485_ADDR  (0x03) /* EEPROM $03: rs-485 unit address */
#define EE_ADDR_GLOB_ADDR (0x04) /* EEPROM $04: rs-485 global address */
#define EE_VALUE_SENTINEL (0xb1) /* EEPROM sentinal byte value */
#define EE_DEFAULT_SPEED  ('5')  /* default baud rate code */
#define UNIT_DISABLED     (0xff) /* address code if unit unit has no address */

//
// Digital output pin numbers for the lights
// (a high output turns on the LEDs)
//                       BL R2 R1  Y  G
const int tree_port[] = {10, 7, 6, 8, 9, 14, 16};
//                       #0 #1 #2 #3 #4  #5  #6

//
// Other output pin numbers
// 
#define PIN_485_DRIVER_ENABLE	 (2)	/* 1=RS-485 driver enabled */
#define PIN_485_RECEIVER_DISABLE (3)	/* 0=RS-485 receiver enabled */
bool rs_485_enabled = false;			/* should we even try to talk to the RS-485 port? */

//
// These LightBlinkers handle our flashing and strobing.
// In each case, they sequence through one or more lights
// at each flash.
// 
#define MAX_SEQUENCE    (64)
#define SEQUENCE_ERROR (254)	/* error in sequence codes */
#define SEQUENCE_OFF   (255)    /* spot in sequence where LEDs are off */
class LightBlinker {
	unsigned int on_period;	  // in mS 
	unsigned int off_period;  // in mS
	bool         cur_state;	  // are we on?
	unsigned int cur_index;   // index into sequence
	unsigned int sequence_length;
	byte         sequence[MAX_SEQUENCE];
	TimerEvent   timer;

public:
	LightBlinker(unsigned int on, unsigned int off, void (*callback)(void));
	void update(void);
	void stop(void);
	void append(int);
	int  length(void);
	void advance(void);
	void start(void);
	void report_state(void);
};

LightBlinker::LightBlinker(unsigned int on, unsigned int off, void (*callback)(void))
{
	timer.set(0, callback);
	timer.disable();
	cur_state = false;
	cur_index = 0;
	sequence_length = 0;
	on_period = on;
	off_period = off;
}

int LightBlinker::length(void)
{
	return sequence_length;
}

void LightBlinker::append(int v)
{
	if (sequence_length < MAX_SEQUENCE) {
		sequence[sequence_length++] = v;
	}
}

void LightBlinker::report_state(void)
{
	// report state as cur_state (R or S) then "X" (off) or "<index>@<sequence>" + "$"
	int i = 0;
	Serial.write(cur_state ? 'R' : 'S');
	if (sequence_length > 0) {
		Serial.write(cur_index + '0');
		Serial.write('@');
		for (i = 0; i < sequence_length; i++) {
			if (sequence[i] == SEQUENCE_OFF) {
				Serial.write('_');
			} else if (i >= COUNTOF(tree_port)) {
				Serial.write('?');
			} else {
				if (i < strlen(THIS_DEVICE_COLOR_MAP)) {
					Serial.write(THIS_DEVICE_COLOR_MAP[i]);
				} else {
					Serial.write(sequence[i] + '0');
				}
			}
		}
	} else {
		Serial.write('X');
	}
	Serial.write('$');
}

void LightBlinker::advance(void)
{
	// If we have a sequence of one item, we will just flash that one on and off
	// If we have no off_period, it's the same as the on_period
	if (sequence_length < 2) {
		if (cur_state) {
			if (sequence[0] != SEQUENCE_OFF && sequence[0] < COUNTOF(tree_port)) {
				digitalWrite(tree_port[sequence[0]], LOW);
			}
			cur_state = false;
			if (off_period > 0)
				timer.setPeriod(off_period);
		} else {
			if (sequence[0] != SEQUENCE_OFF && sequence[0] < COUNTOF(tree_port)) {
				digitalWrite(tree_port[sequence[0]], HIGH);
			}
			cur_state = true;
			if (off_period > 0)
				timer.setPeriod(on_period);
		}
		return;
	}
	
	// Otherwise we just change to the next light in the sequence
	// If we have no off_period, just switch to the next one. Otherwise,
	// only advance on the "on" transition, so we quickly flash each in
	// turn.
	if (sequence_length > MAX_SEQUENCE)
		sequence_length = MAX_SEQUENCE;

	if (off_period == 0) {
		cur_state = true;
		if (sequence[cur_index] != SEQUENCE_OFF && sequence[cur_index] < COUNTOF(tree_port)) {
			digitalWrite(tree_port[sequence[cur_index]], LOW);
		}
		cur_index = (cur_index + 1) % sequence_length;
		if (sequence[cur_index] != SEQUENCE_OFF && sequence[cur_index] < COUNTOF(tree_port)) {
			digitalWrite(tree_port[sequence[cur_index]], HIGH);
		}
	}
	else {
		if (cur_state) {
			if (sequence[cur_index] != SEQUENCE_OFF && sequence[cur_index] < COUNTOF(tree_port)) {
				digitalWrite(tree_port[sequence[cur_index]], LOW);
			}
			timer.setPeriod(off_period);
			cur_state = false;
		}
		else {
			cur_index = (cur_index + 1) % sequence_length;
			if (sequence[cur_index] != SEQUENCE_OFF && sequence[cur_index] < COUNTOF(tree_port)) {
				digitalWrite(tree_port[sequence[cur_index]], HIGH);
			}
			timer.setPeriod(on_period);
			cur_state = true;
		}
	}
}

void LightBlinker::update(void)
{
	timer.update();
}

void LightBlinker::stop(void)
{
	timer.disable();
	sequence_length = 0;
}

void LightBlinker::start(void)
{
	if (sequence_length > 0) {
		cur_index = 0;
		cur_state = true;
		if (sequence[0] != SEQUENCE_OFF && sequence[0] < COUNTOF(tree_port)) {
			digitalWrite(tree_port[sequence[0]], HIGH);
		}
		timer.reset();
		timer.setPeriod(on_period);
		timer.enable();
	}
	else {
		stop();
	}
}

const int CSM_BUFSIZE = 64;
class CommandStateMachine {
private:
	enum StateCode {
		CollectAddressState,
		CollectNState,
		EndState,
		ErrorState,
		FlashState,
		IdleState,
		LightSetState,
		SetAgState,
		SetState,
		SetRSpeedState,
		SetUSpeedState,
		StartState,
		StrobeState,
	} state;
	byte LEDset;
	byte command_in_progress;
	byte buffer[CSM_BUFSIZE];
	byte address_count;
	byte buffer_idx;
	bool source_485;
	bool next_byte_msb;
	bool next_byte_literal;
public:
	void accept(int inputchar, bool from_485=false);
	bool accept_led_name(int inputchar);
	bool append_buffer(byte value);
	void begin(void);
	void end_cmd(void);
	void error(void);
	void reset(void);
};	

void CommandStateMachine::error(void) {
	digitalWrite(tree_port[0], HIGH);
	state = ErrorState;
}

void CommandStateMachine::end_cmd(void) {
	state = EndState;
}

void flash_lights(void);
void strobe_lights(void);
LightBlinker flasher(200, 0, flash_lights);
LightBlinker strober(50, 2000, strobe_lights);
CommandStateMachine csm;
byte my_address = UNIT_DISABLED;
byte global_address = UNIT_DISABLED;

void setup() {
	int i=0;
	//
	// digital output mode setting
	//
	for (i = 0; i < COUNTOF(tree_port); i++) {
		pinMode(tree_port[i], OUTPUT);
	}
	//
	// Cycle through all the lights at power-on
	// to test that they all work
	//
	for (i = 0; i < COUNTOF(tree_port); i++) {
		digitalWrite(tree_port[i], HIGH);
		delay(200);
		all_off(true);
	}

	default_eeprom_settings();
	flasher.stop();
	strober.stop();
	digitalWrite(tree_port[0], HIGH);
	start_usb_serial();
	my_address = EEPROM.read(EE_ADDR_485_ADDR);
	global_address = EEPROM.read(EE_ADDR_GLOB_ADDR);
	
	// By default, the hardware disables the RS-485 transceiver chip.
	// Here, we'll activate the control lines and either set the transceiver
	// to receive or leave it disabled.
	pinMode(PIN_485_DRIVER_ENABLE, OUTPUT);
	digitalWrite(PIN_485_DRIVER_ENABLE, LOW);
	//            __
	// We set the RE line high before enabling it as an output. This
	// will ensure that it's sending a high signal from the start (and
	// will cause the pin's internal pull-up resistor to be activated
	// as well during the time before it is switched to output mode).
	digitalWrite(PIN_485_RECEIVER_DISABLE, HIGH);
	pinMode(PIN_485_RECEIVER_DISABLE, OUTPUT);
	if (my_address != UNIT_DISABLED) {
		enable_485_serial();
	}
	digitalWrite(tree_port[0], LOW);
	csm.begin();
}

void default_eeprom_settings(void) {
	if (EEPROM.read(EE_ADDR_SENTINEL) != EE_VALUE_SENTINEL) {
		// apparently unset; set to "factory defaults"
		EEPROM.write(EE_ADDR_USB_SPEED, EE_DEFAULT_SPEED);
		EEPROM.write(EE_ADDR_485_SPEED, 0); // 0=disabled
		EEPROM.write(EE_ADDR_485_ADDR, UNIT_DISABLED);
		EEPROM.write(EE_ADDR_GLOB_ADDR, UNIT_DISABLED);
		EEPROM.write(EE_ADDR_SENTINEL, EE_VALUE_SENTINEL);
		return;
	}

	int speed = EEPROM.read(EE_ADDR_USB_SPEED);
	if (!((speed >= '0' && speed <= '9') 
	|| (speed >= 'a' && speed <= 'c') 
	|| (speed >= 'A' && speed <= 'C'))) {
		// baud rate setting invalid; return to default
		EEPROM.write(EE_ADDR_USB_SPEED, EE_DEFAULT_SPEED);
	}
	disable_485_serial();
}

long decode_baud_rate(byte code) {
	long speed = 9600;

	switch (code) {
		case '0': speed =    300; break;
		case '1': speed =    600; break;
		case '2': speed =   1200; break;
		case '3': speed =   2400; break;
		case '4': speed =   4800; break;
		case '5': speed =   9600; break;
		case '6': speed =  14400; break;
		case '7': speed =  19200; break;
		case '8': speed =  28800; break;
		case '9': speed =  31250; break;
		case 'a':
		case 'A': speed =  38400; break;
		case 'b':
		case 'B': speed =  57600; break;
		case 'c':
		case 'C': speed = 115200; break;
	}
	return speed;
}

void start_usb_serial(void) {
	long speed = decode_baud_rate(EEPROM.read(EE_ADDR_USB_SPEED));
	Serial.begin(speed);
	while (!Serial);
}

void enable_485_serial(void) {
	/* turn on the transceiver in receiver mode */
	digitalWrite(PIN_485_DRIVER_ENABLE, LOW);
	digitalWrite(PIN_485_RECEIVER_DISABLE, LOW);

	/* tell the rest of the firmware to pay attention to the port */
	rs_485_enabled = true;

	/* set up the Serial1 interface and set the baud rate on the UART */
	start_485_serial();
}

void disable_485_serial(void) {
	/* turn off the transceiver chip entirely */
	digitalWrite(PIN_485_DRIVER_ENABLE, LOW);
	digitalWrite(PIN_485_RECEIVER_DISABLE, HIGH);

	/* tell the rest of the firmware to ignore the port */
	rs_485_enabled = false;
}

void start_485_serial(void) {
	byte speed_code = EEPROM.read(EE_ADDR_485_SPEED);
	if (speed_code > 0) {
		long speed = decode_baud_rate(speed_code);
		Serial1.begin(speed);
		while (!Serial1);
	} else {
		disable_485_serial();
	}
}

//
// all_off(): reset device to all off, no flashing
//
void all_off(bool reset_state) {
	if (reset_state) {
		flasher.stop();
		strober.stop();
	}
	for (int i=0; i < COUNTOF(tree_port); i++) {
		digitalWrite(tree_port[i], LOW);
	}
}

void report_LED_state(void)
{
  int i = 0;

  Serial.write('L');
  for (i = 0; i < COUNTOF(tree_port); i++) {
	if (i < strlen(THIS_DEVICE_COLOR_MAP)) {
		Serial.write(digitalRead(tree_port[i]) == HIGH ? THIS_DEVICE_COLOR_MAP[i] : '_');
	} else {
		Serial.write(digitalRead(tree_port[i]) == HIGH ? i+'0' : '_');
	}
  }
  Serial.write('$');
  Serial.write('F');
  flasher.report_state();
  Serial.write('S');
  strober.report_state();
  Serial.write('\n');
}

void report_device_state(void)
{
	byte b;
	Serial.write('Q');	// query response
	Serial.write('B');	// device model = busylight
	Serial.write('=');	// settings
	if (my_address == UNIT_DISABLED) {
		Serial.write('_');
	} else if (my_address < 64) {
		Serial.write(my_address + '0');
	} else {
		Serial.write('*');
	}
	Serial.write(EEPROM.read(EE_ADDR_USB_SPEED)); // USB speed
	if ((b = EEPROM.read(EE_ADDR_485_SPEED)) == 0) {
		Serial.write('_');
	} else {
		Serial.write(b);
	}
	if (global_address == UNIT_DISABLED) {
		Serial.write('_');
	} else if (global_address < 16) {
		Serial.write(global_address + '0');
	} else {
		Serial.write('*');
	}
	Serial.write('$');	// end of settings
	Serial.write(SERIAL_VERSION_STAMP);	// hardware version, firmware version, serial number
	Serial.write('\n'); // end of query response
}

bool set_baud_rate(byte baud_code) {
	if ((baud_code >= '0' && baud_code <= '9') 
	|| (baud_code >= 'A' && baud_code <= 'C')
	|| (baud_code >= 'a' && baud_code <= 'c')) {
		EEPROM.write(EE_ADDR_USB_SPEED, baud_code);
		start_usb_serial();
		return true;
	}
	return false;
}

bool set_485_baud_rate(byte baud_code) {
	if (baud_code == 0 || my_address == UNIT_DISABLED) {
		EEPROM.write(EE_ADDR_485_SPEED, 0);
		return true;
	}
	if ((baud_code >= '0' && baud_code <= '9') 
	|| (baud_code >= 'A' && baud_code <= 'C')
	|| (baud_code >= 'a' && baud_code <= 'c')) {
		EEPROM.write(EE_ADDR_485_SPEED, baud_code);
		start_485_serial();
		return true;
	}
	return false;
}

// begin: start off the state machine
void CommandStateMachine::begin(void) {
	source_485 = false;
	reset();
}

// reset: reset the state machine back to the start state
void CommandStateMachine::reset(void) {
	state = IdleState;
	address_count = 0;
	command_in_progress = 0;
	next_byte_literal = false;
	next_byte_msb = false;
	buffer_idx = 0;
	LEDset = 0;
	for (int i=0; i<CSM_BUFSIZE; i++) 
		buffer[i] = 0;
}
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
void loop() {
	//
	// loop forever, adjusting the lights as each
	// command comes in. We will silently ignore
	// invalid commands (with the side effect that
	// it's perfectly fine to throw newlines in the
	// stream).
	//
	flasher.update();
	strober.update();

	if (Serial.available() > 0) {
		csm.accept(Serial.read(), false);
	}
	if (rs_485_enabled && Serial1.available() > 0) {
		csm.accept(Serial1.read(), true);
	}
}

// flash a single light on/off, or sequence through a list at the on cadence.
void flash_lights(void)
{
	flasher.advance();
}

void strobe_lights(void)
{
	strober.advance();
}

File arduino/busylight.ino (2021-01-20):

/*
** Steve Willoughby <steve@alchemy.com>
**
** Simple busylight indicator, controlled via USB serial commands.
** To use, open the USB device as a serial port and send single 
** character commands to it:
**
**  X all lights off
**  G only green layer on
**  Y only yellow layer on
**  R only red layer #1 on
**  2 only red layer #2 on
**  ! only both red layers on
**  # alternately flash red layers
**
** The alphabetic commands may be sent in either case.
** Any other bytes are simply ignored.
**
** The physical LED tree is stacked like so:
**
**                    RED 2   ==================
**                                    ||
**                    RED 1   ==================
**                                    ||
**                    YELLOW  ==================
**                                    ||
**                    GREEN   ==================
**                                    ||
**                                    ||
**                                    ||
**                                    ||
**                                    ||
**                                    ||
**                                    ||
*/

const int tree_green  = 6
const int tree_yellow = 7
const int tree_red_1  = 8
const int tree_red_2  = 9
static int tree_flash = 0

void setup() {
	Serial.begin(9600);
	pinMode(tree_green, OUTPUT);
	pinMode(tree_yellow, OUTPUT);
	pinMode(tree_red_1, OUTPUT);
	pinMode(tree_red_2, OUTPUT);
	all_off();
	digitalWrite(tree_red_2, LOW);
	delay(200);
	digitalWrite(tree_red_1, LOW);
	delay(200);
	digitalWrite(tree_yellow, LOW);
	delay(200);
	digitalWrite(tree_green, LOW);
	delay(200);
	all_off();
}

void all_off() {
	tree_flash = 0;
	digitalWrite(tree_green, LOW);
	digitalWrite(tree_yellow, LOW);
	digitalWrite(tree_red_1, LOW);
	digitalWrite(tree_red_2, LOW);
}

void loop() {
	while (Serial.available() > 0) {
		switch (Serial.read()) {
			case 'G':
			case 'g':
				all_off();
				digitalWrite(tree_green, HIGH);
				break;
			case 'Y':
			case 'y':
				all_off();
				digitalWrite(tree_yellow, HIGH);
				break;
			case 'R':
			case 'r':
				all_off();
				digitalWrite(tree_red_1, HIGH);
				break;
			case '2':
				all_off();
				digitalWrite(tree_red_2, HIGH);
				break;
			case '!':
				all_off();
				digitalWrite(tree_red_1, HIGH);
				digitalWrite(tree_red_2, HIGH);
				break;
			case 'X':
			case 'x':
				all_off();
				break;
			case '#':
				tree_flash = 1;
		}
	}
	if (tree_flash == 1) {
		all_off();
		tree_flash = 2;
		digitalWrite(tree_red_1, HIGH);
		delay(250);
	} else if (tree_flash == 2) {
		all_off();
		tree_flash = 1;
		digitalWrite(tree_red_2, HIGH);
		delay(250);
	}
}

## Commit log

2021-01-21 fixed typos, moved to sketch folder
    [busylight.ino]
2021-01-31 updated Arduino code and documentation
2021-01-31 added schematic for hardware
    [busylight.sch]
2021-06-18 updated busylight(1) with device search feature
2022-03-24 updated schematic
    [busylight.sch]
2022-03-24 added PCB files
    [busylight_shield.GBL, busylight_shield.GBO, busylight_shield.GBS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]
2022-04-15 removed experimental note about PCB after successful test
2023-10-26 allow device address range 0-63
2023-10-28 update PCB for v2 hardware
2023-10-28 added v2 fabrication gerber files
    [busylight_shield.GBL, busylight_shield.GBO, busylight_shield.GBS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]
2024-09-30 cleaned up
    [busylight.kicad_sch, busylight_schematic.kicad_sch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]
